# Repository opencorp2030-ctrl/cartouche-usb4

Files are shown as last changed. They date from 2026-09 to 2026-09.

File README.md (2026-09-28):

# CARTOUCHE Éclair V1 — a tiny USB4 NVMe drive for a local AI

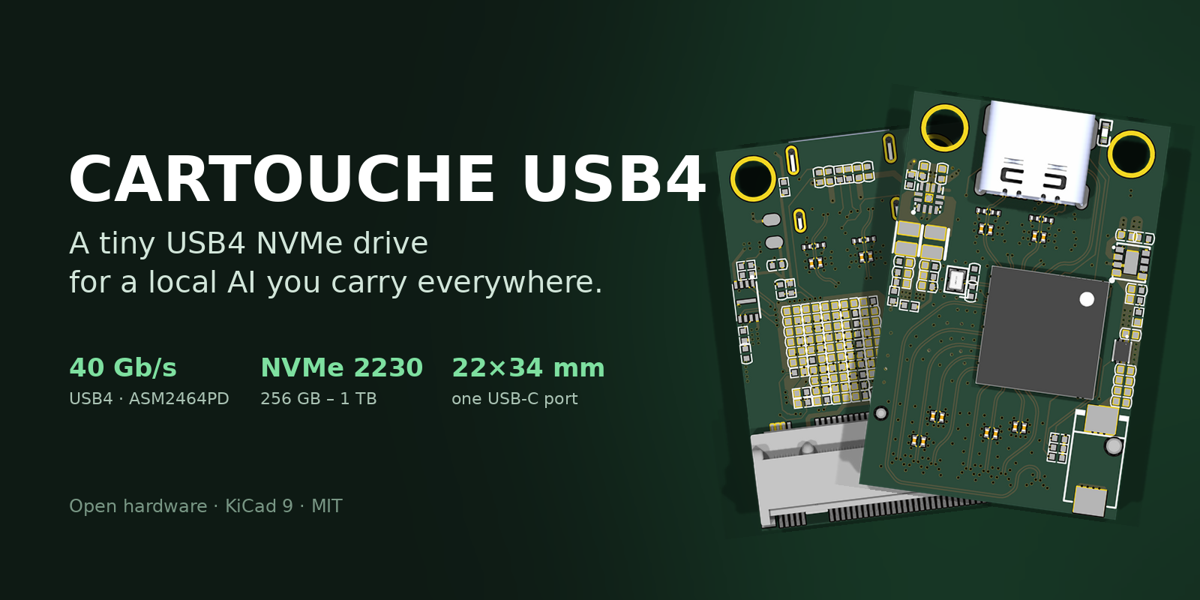
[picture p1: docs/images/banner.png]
CARTOUCHE Éclair V1


CARTOUCHE is a way to store heavy AI models and run them easily and fast, while
keeping your data from going to third-party servers.

Website: [cartouche.candygate.eu](https://cartouche.candygate.eu/eclair.html)

| | |
|---|---|
| Board | 22.0 × 33.7 mm, 4 layers, 1.6 mm |
| USB4 controller | ASMedia ASM2464PD, 40 Gb/s, PCIe 4.0 x4 |
| Storage | M.2 2230 NVMe SSD, 256 GB – 2 TB |
| Case | aluminium, 25 × 65.7 × 15.6 mm with the cooling fins, laser-engraved, 3 colours |
| Expected speed | ≈ 3.5 GB/s on USB4 / Thunderbolt, ≈ 1 GB/s on USB 3.2 (not measured yet) |
| In the box | USB-C 40 Gb/s cable + USB-A cable |

| Full model | Inside (case transparent) |
|---|---|
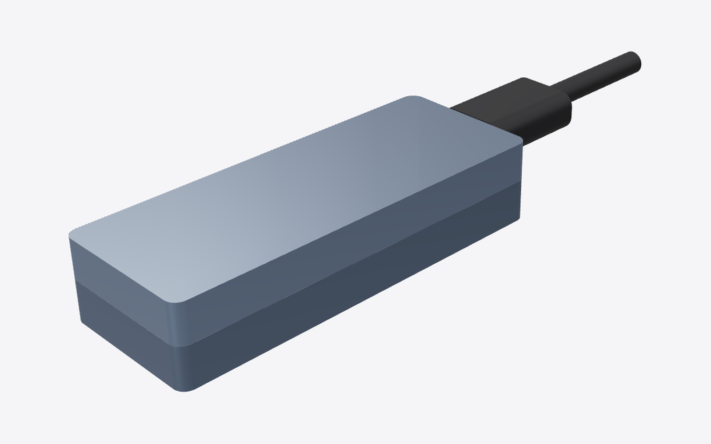
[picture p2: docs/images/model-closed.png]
full model
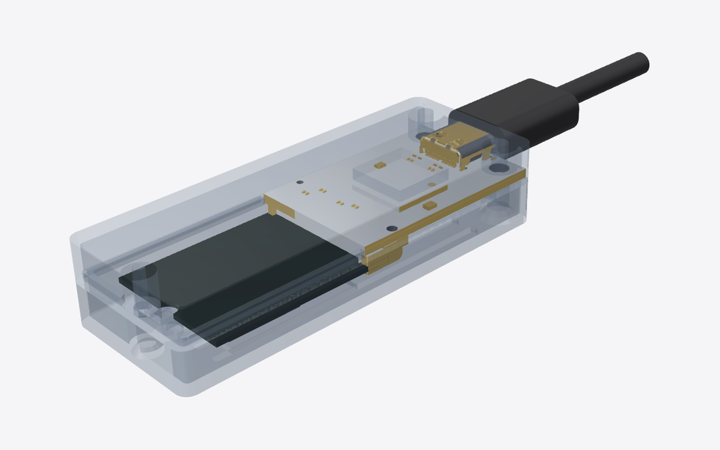
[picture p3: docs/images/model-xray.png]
inside
|  |  |
| **Exploded view** | **Board + SSD** |
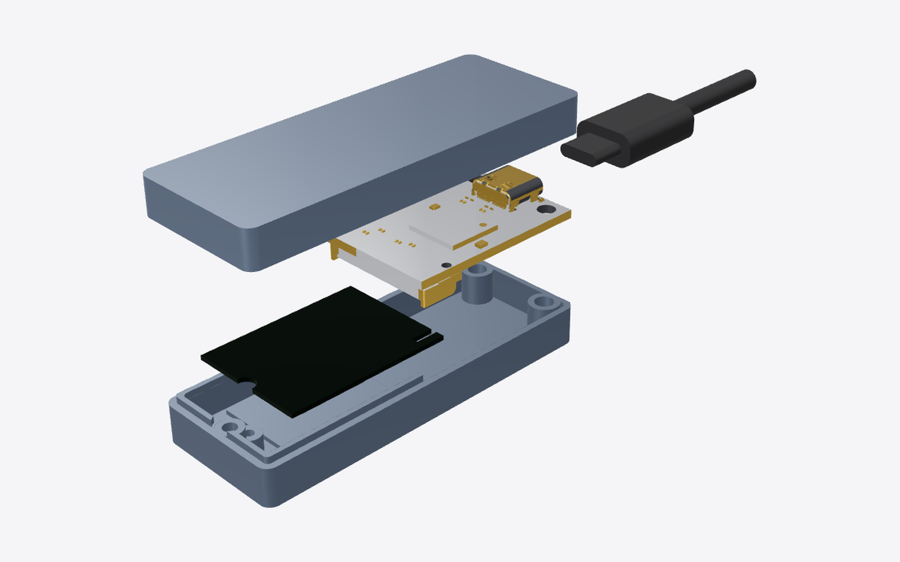
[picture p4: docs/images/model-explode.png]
exploded
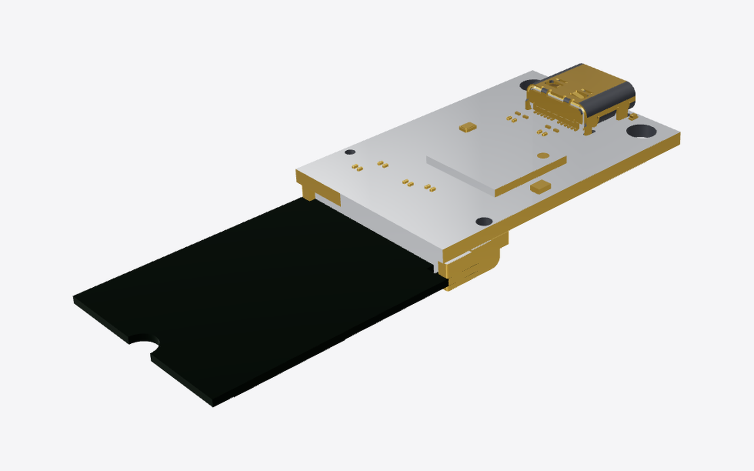
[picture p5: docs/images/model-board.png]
board and SSD
|  |  |
| **Cut through the middle** | **Underside, M3 screws** |
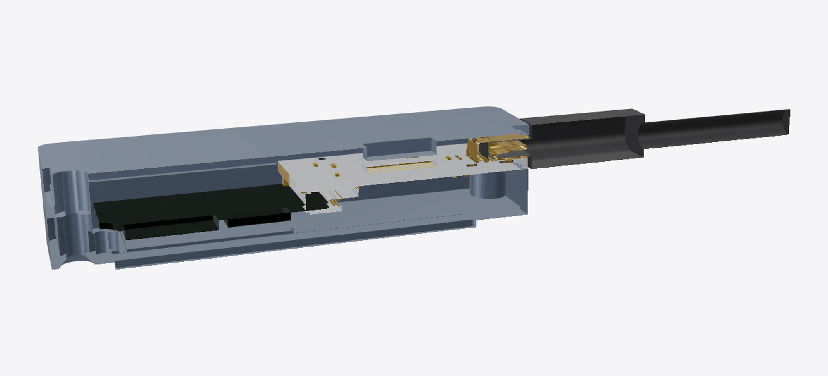
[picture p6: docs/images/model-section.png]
section
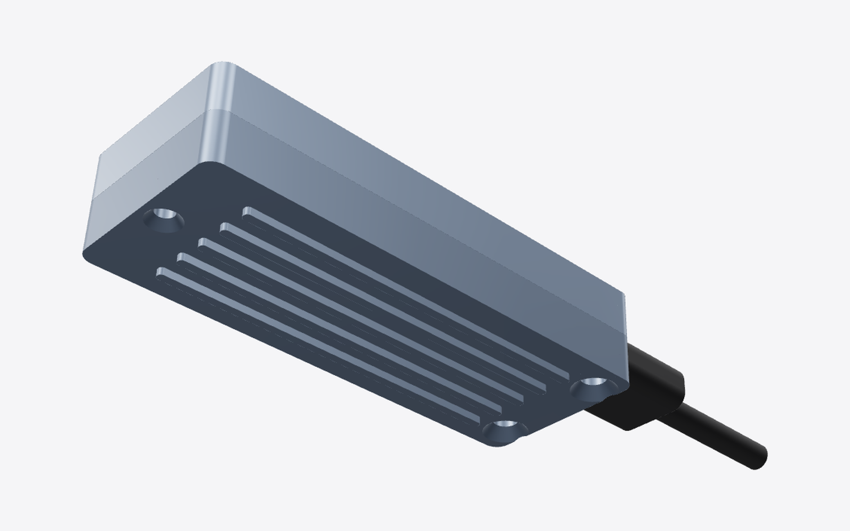
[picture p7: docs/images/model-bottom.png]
underside
|  |  |

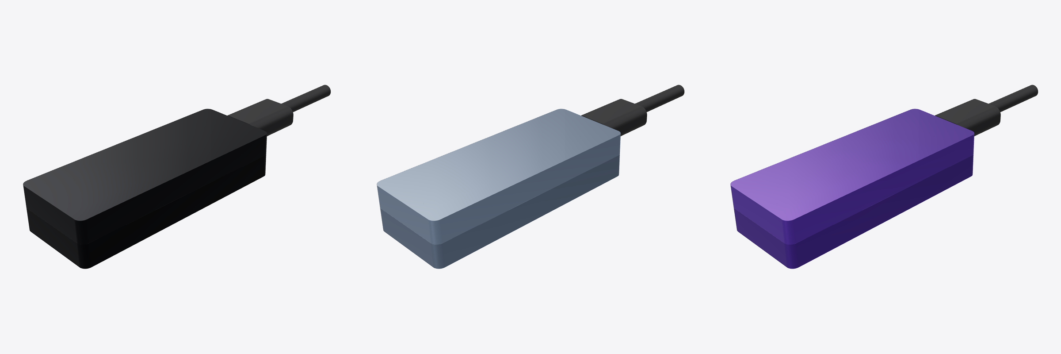
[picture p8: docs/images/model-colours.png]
three colours


| PCB, top | PCB, bottom |
|---|---|
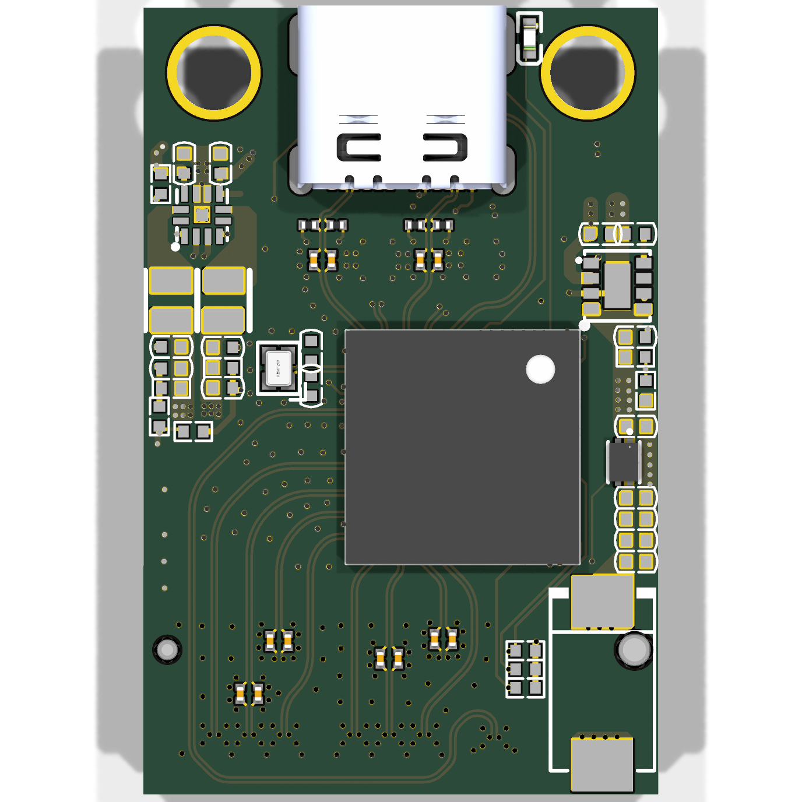
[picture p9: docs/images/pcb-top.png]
PCB top
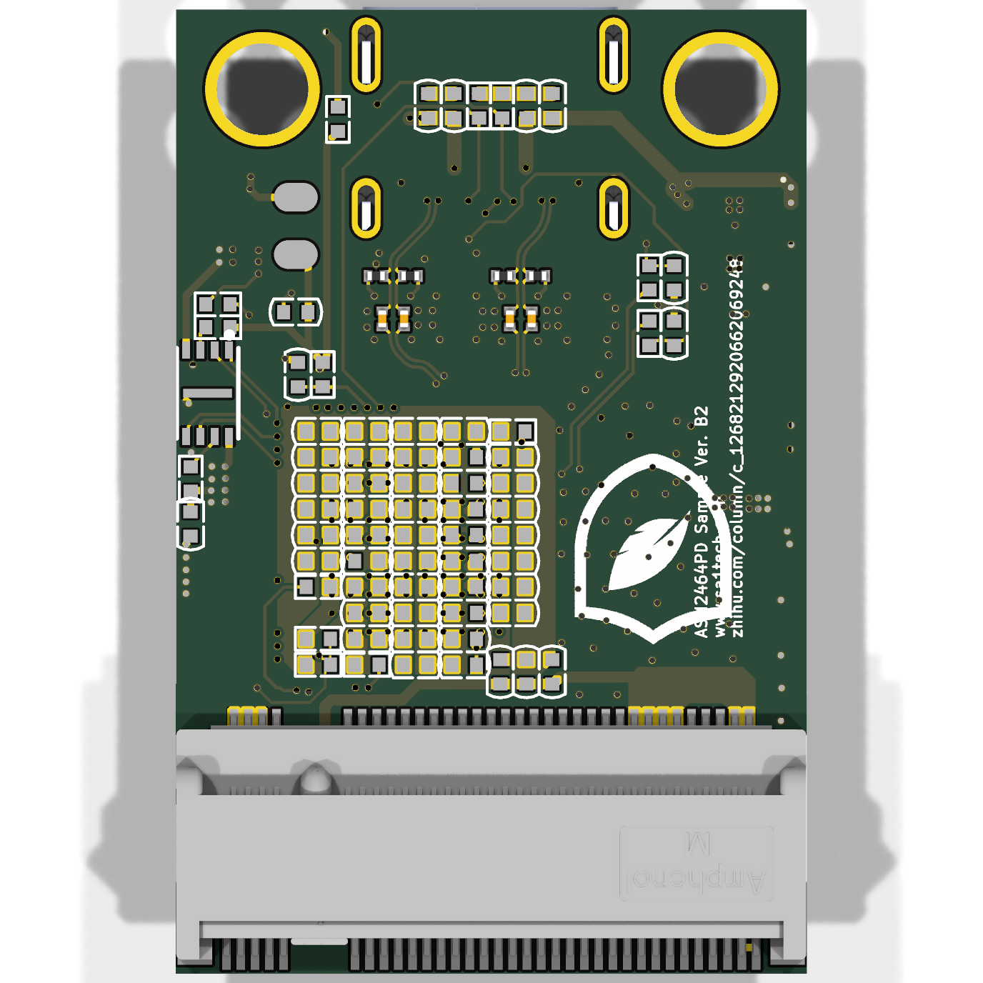
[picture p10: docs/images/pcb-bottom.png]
PCB bottom
|  |  |

## Why I made this

I got the idea because I have a lot of other projects with AI, and this was a real
problem. I like solving the problems I have.

Why my own drive (Éclair) and not just USB keys: because I want it to be useful
for devs and to be a good deal. That's actually why I set up the developer program.

## Wiring

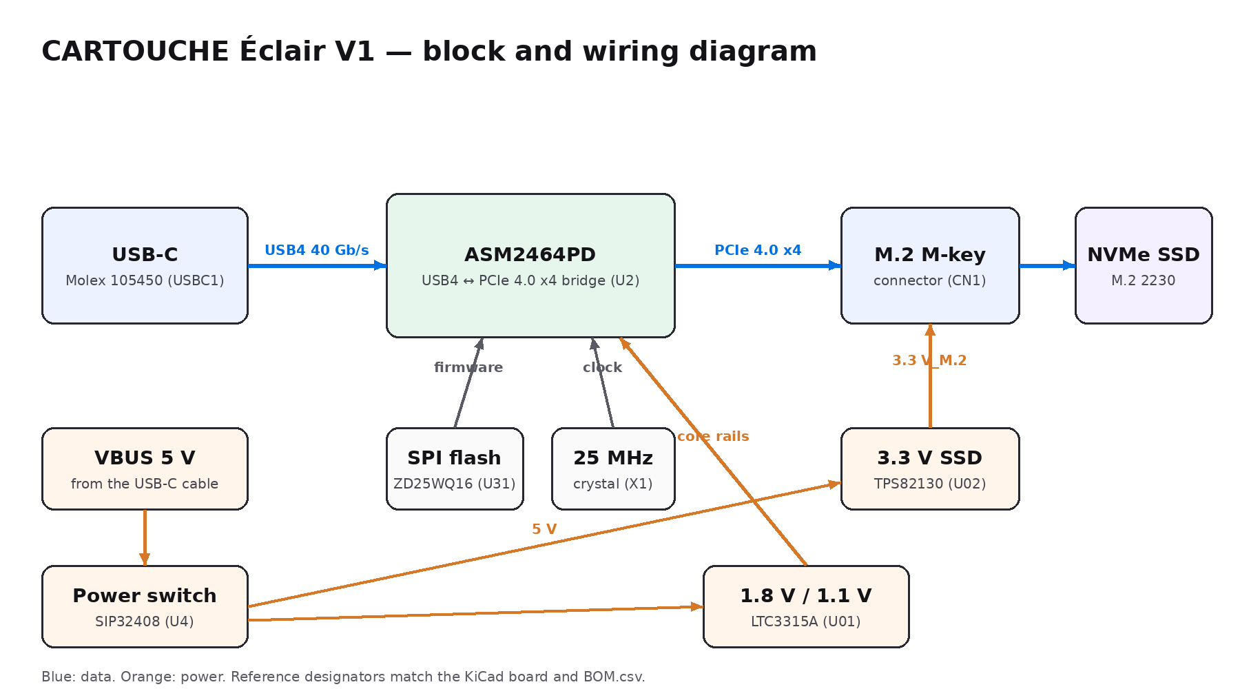
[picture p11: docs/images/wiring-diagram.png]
wiring diagram


Full schematic: [`pcb/cartouche-usb4.kicad_sch`](pcb/cartouche-usb4.kicad_sch) ·
[PDF](docs/schematic.pdf)

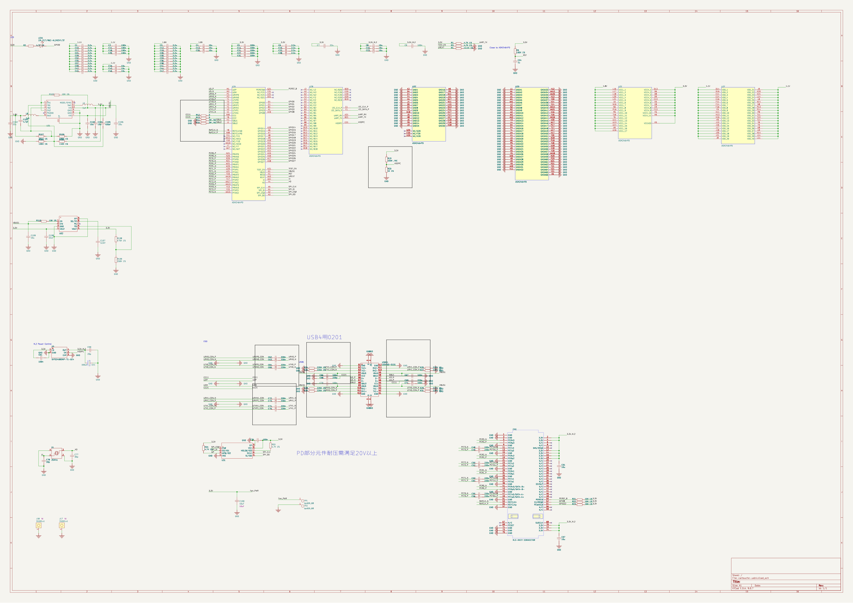
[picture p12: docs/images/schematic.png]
schematic


## What's in the repository

| Folder | Content |
|---|---|
| [`BOM.csv`](BOM.csv) | every part, with manufacturer part numbers and supplier links that work from France |
| [`pcb/`](pcb) | KiCad 9 project (`.kicad_pro`, `.kicad_sch`, `.kicad_pcb`, symbol library), Gerbers + drills (`fab/cartouche-usb4-gerbers.zip`), pick-and-place, board STEP, import scripts |
| [`cad/`](cad) | **case source** (`eclair_v1.py`, CadQuery), and in `cad/out/`: case base and lid, SSD 2230 and USB-C plug (STEP + STL), the board as a printable mock-up (STL), and **`eclair_v1_assembly.step`, the full assembly with the electronics** |
| [`firmware/`](firmware) | how the drive enumerates (NVMe over USB4, UAS over USB 3), flashing the ASMedia firmware, `eclair_check.py` (link and speed check) |
| [`docs/`](docs) | [costs per unit](docs/COSTS.md), images |

## The case

The case will be made of good-quality aluminium, both to protect against shocks and
to get rid of the heat. It will be engraved so the info doesn't wear off over time.
Arranging everything as well as possible is pretty complicated. I'm really happy
with it, especially the purple colour of the case, which you can pick as an option
on the website.

| Part | Detail |
|---|---|
| Halves | base + lid, split under the board |
| Board + closing | 2 × M3 × 12 countersunk screws, from below, through the board's Ø3.2 holes into the lid |
| SSD | in the M.2 connector (LOTES APCI0113-P001A, 4.75 mm, since v1.3: the ARGOSY NASM0-S6701-TPH4 is out of stock): card 3.15 mm under the board, edge seated 1.75 mm past the connector posts (LOTES drawing AP-APCI0113, to confirm on the real part); M2 screw on a standoff of the base |
| Assembly order | plug the SSD into the board outside the case, press it flat, lay board + SSD into the base, M2 screw, then the lid |
| Rear | 1 × M2 × 10 screw |
| USB-C | receptacle flush with the front; plug model included, mated and checked |
| Cooling (passive, no fan) | lid boss + 1 mm thermal pad on the ASM2464PD; base boss + 1 mm thermal pad (20 × 22 mm) under the SSD; 5 fins under the base (1 mm). Leaves232 warns the ASM2464PD overheats and disconnects without cooling (he used a laptop fan): to be checked with a 15 min transfer on the aluminium prototype |
| Interference check | no overlap between board, SSD, plug, base and lid |
| Fit test | print `case_base.stl`, `case_lid.stl`, `ssd_2230.stl`, `board_mockup.stl` (the mock-up has a 1.0 mm card slot cut in the connector); values to confirm are marked `CHECK` in `eclair_v1.py` |
| Fit check (CadQuery) | 0 mm³ overlap between SSD, board, case base, lid and USB-C plug |

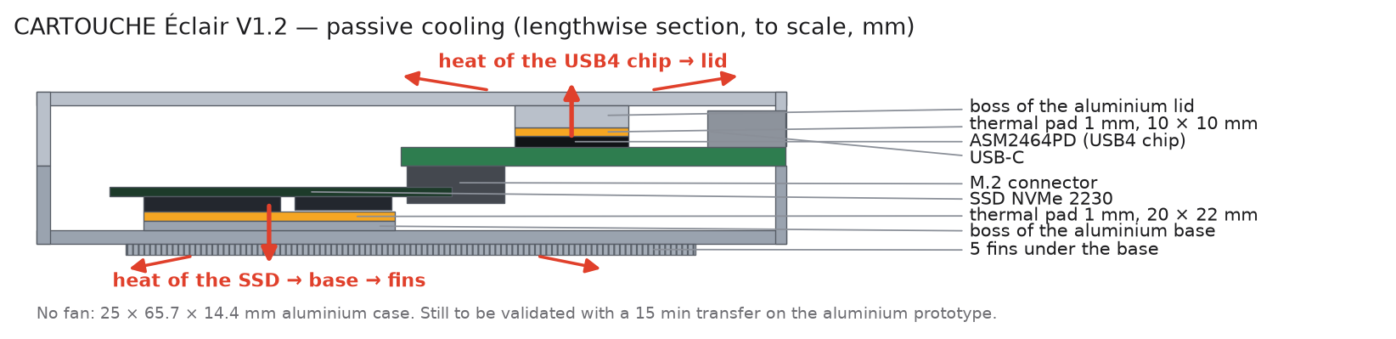
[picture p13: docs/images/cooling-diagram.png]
cooling diagram


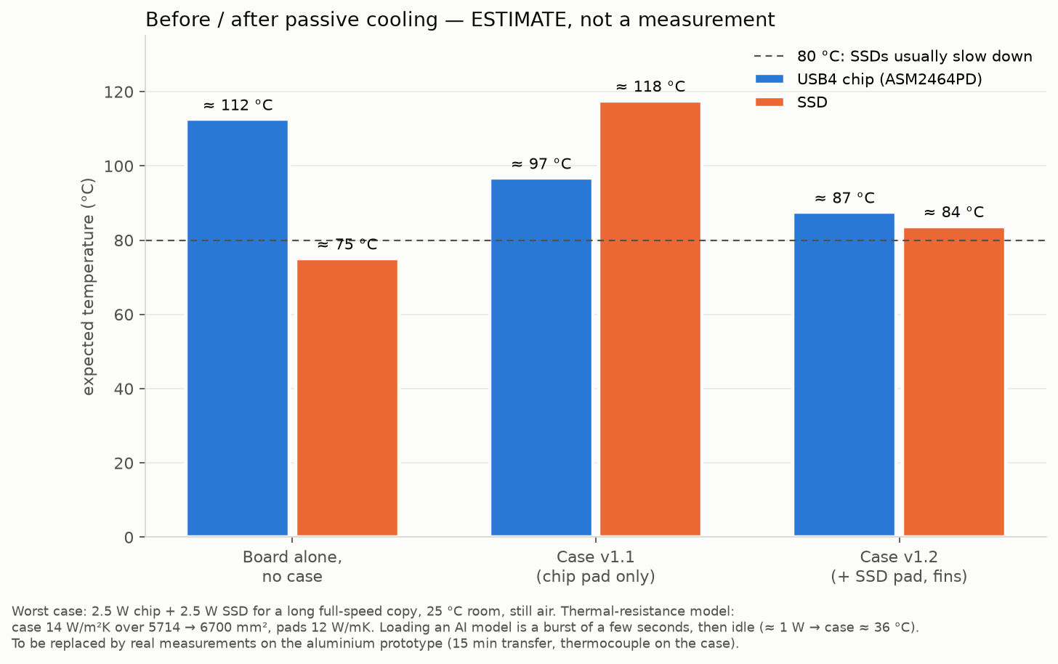
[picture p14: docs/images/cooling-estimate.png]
cooling estimate, before / after


The chart is an estimate from a simple thermal-resistance model (assumptions under the chart), not a measurement.

## Éclair Dock (optional): under the desk

| Top: Éclair slides in | Desk side: rails, screw bosses, air slots |
|---|---|
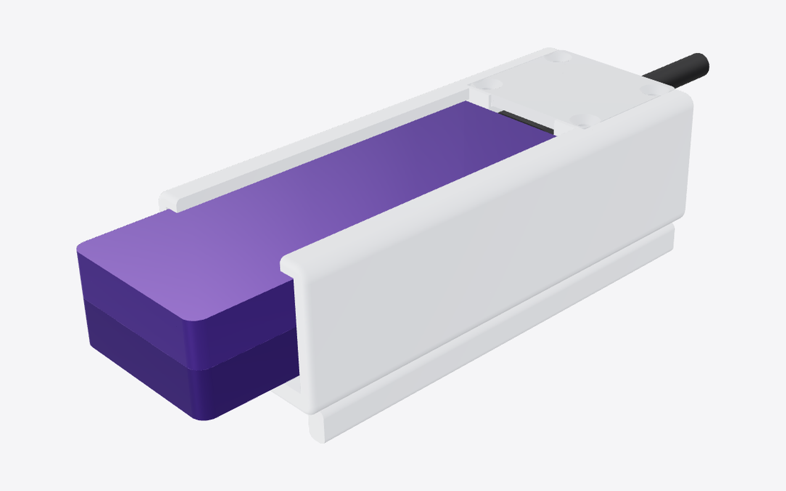
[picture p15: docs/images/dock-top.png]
dock top
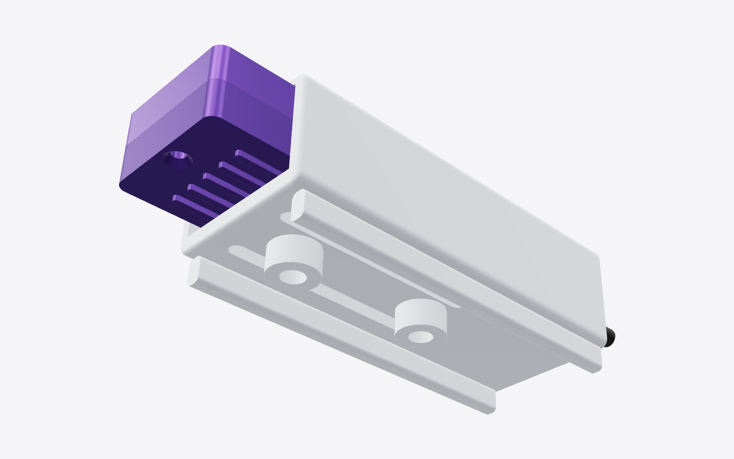
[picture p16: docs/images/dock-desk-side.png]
dock desk side
|  |  |

| Part | Detail |
|---|---|
| Size | 29.9 × 73.8 × 27.2 mm, CNC aluminium, polished |
| Mounting | 2 countersunk wood screws Ø4 under the desk (reachable with Éclair out) |
| Holding Éclair | Éclair hangs upside down on two lips (engraved lid facing the room), 0.25 mm clearance, 14 mm sticks out to grip it |
| Cable | USB4 40 Gb/s 0.8 m cable, its plug clamped in the rear block (plate + 4 × M2 countersunk): sliding Éclair in plugs it, pulling it out unplugs it |
| Airflow | 2 rails + 2 bosses keep the plate 5 mm off the desk; slots above the fins let warm air out along that gap (see diagram) |
| Fit check (CadQuery) | 0 mm³ overlap between dock, clamp, case and plug |
| Files | `cad/out/dock_body.step/.stl`, `dock_clamp.step/.stl`, `eclair_dock_assembly.step` (with the electronics) |

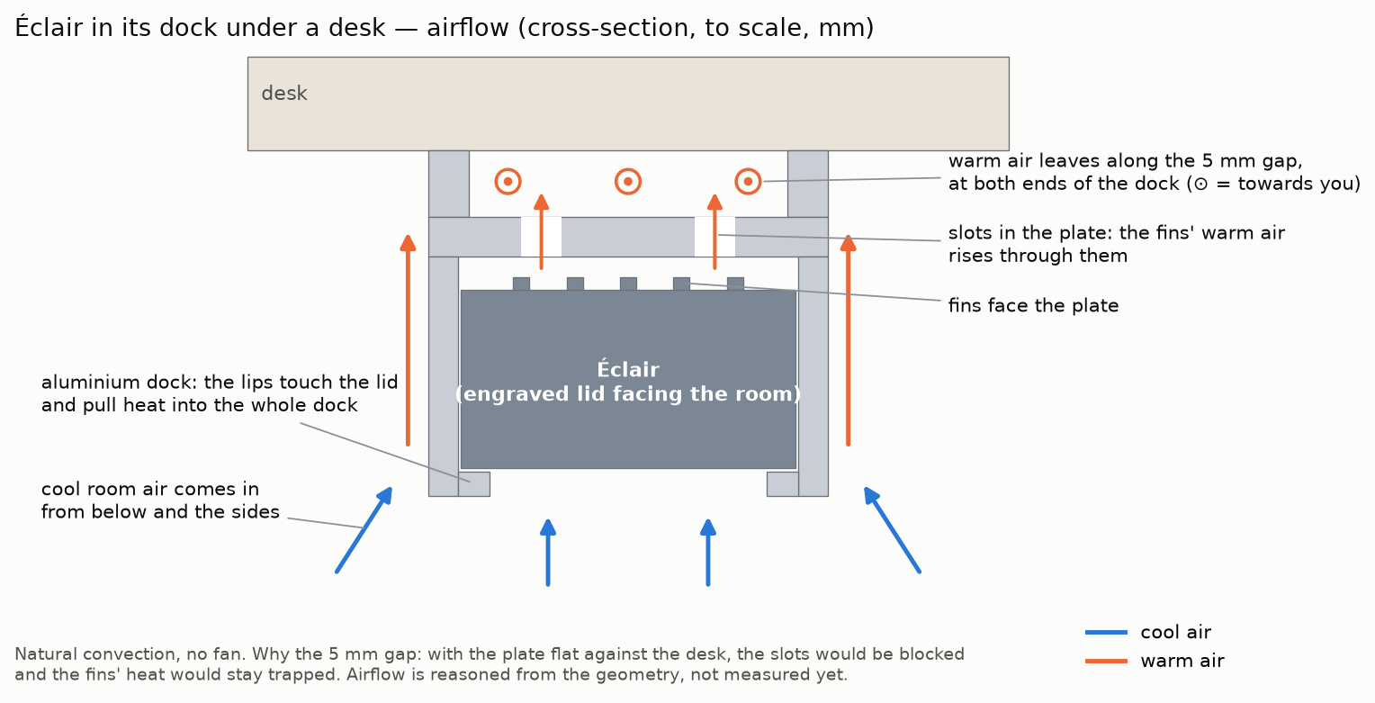
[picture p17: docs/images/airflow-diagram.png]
airflow under the desk


**Installing it**: a 1:1 drilling template is in [`docs/dock-drilling-template.pdf`](docs/dock-drilling-template.pdf) (print at 100 %, check the 50 mm bar; generated from the CAD numbers by `cad/make_dock_template.py`). Pilot holes Ø2.5 × 14 mm, desk top 18 mm thick minimum.

**Print test**: print `cad/out/dock_body.stl` (rails flat on the bed), `dock_clamp.stl`, `case_base.stl` and `case_lid.stl` in PLA/PETG, 0.2 mm layers. The 0.25 mm clearance is meant for machined aluminium; on an FDM print, sand the lips lightly if Éclair rubs.

3D films of the dock (object, installation, everyday use, cooling): https://cartouche.candygate.eu/support.html

## Credit: what is mine and what is not

For this prototype, I'd rather start from something that works, even if I have to
adjust it, than start again from zero (no need to reinvent the wheel). All the
ideas, the tests and the code are my work ;)

| From [Leaves232/2230-USB4-SSD-Enclosure-Design](https://github.com/Leaves232/2230-USB4-SSD-Enclosure-Design) (MIT, see [`LICENSE-upstream-MIT`](LICENSE-upstream-MIT)) | Mine |
|---|---|
| schematic, component placement, USB4/PCIe routing (not modified) | KiCad 9 conversion and fab package, smallest outline, case CAD, SSD and cable fit, BOM with suppliers and costs, flashing procedure and check tool, the CARTOUCHE software |

Schematic imported from the original Altium project into KiCad 9
(`pcb/cartouche-usb4.kicad_sch`, symbols in `pcb/ASM2464PD-altium-import.kicad_sym`).

## How to get it made

| Board parameter | Value |
|---|---|
| Layers / material | 4 layers, FR-4 TG150, 1.6 mm |
| Finish / copper | ENIG, 1 oz outer / 0.5 oz inner |
| Impedance | 85 Ω differential pairs on the outer layers |
| Track / space, vias | 3.5 / 3.5 mil, 0.2 mm tented vias |
| Assembly | by the fab (ASM2464PD = 0.46 mm pitch BGA) |
| Copper zones | do not refill in KiCad (from the tested original) |

1. Order the board assembled (PCBA).
2. Plug the SSD, place the thermal pad.
3. Screw the board and SSD into the base, close the lid.
4. Flash the firmware once ([`firmware/`](firmware)).

## Status

We're working on testing our own Éclair boards, and then, why not, making a sort of
mini computer you plug into your PC that runs the model on its own RAM and its own
storage.

## Licence

MIT, like the original design. See [`LICENSE`](LICENSE) and
[`LICENSE-upstream-MIT`](LICENSE-upstream-MIT).

## Bill of materials

Same content as [`BOM.csv`](BOM.csv).

| # | Qty | Value | Package | Manufacturer | Part number | Unit price | Link |
|---|---|---|---|---|---|---|---|
| 1 | 3 | 22uF | C0402 | Samsung | GRM155R60J226ME11D | CNY 0.22275 | [link](https://www.lcsc.com/search?q=GRM155R60J226ME11D) |
| 2 | 15 | 10uF | C0402 | Samsung | CL05A106MQ5NUNC | CNY 0.02281 | [link](https://www.lcsc.com/search?q=CL05A106MQ5NUNC) |
| 3 | 26 | 2.2uf | C0402 | Samsung | CL05A225KP5NSNC | CNY 0.01346 | [link](https://www.lcsc.com/search?q=CL05A225KP5NSNC) |
| 4 | 16 | 100nF | C0402 | FH | 0402F104M500NT | CNY 0.00481 | [link](https://www.lcsc.com/search?q=0402F104M500NT) |
| 5 | 1 | 1uF | C0402 | FH | 0402X105K6R3NT | CNY 0.00766 | [link](https://www.lcsc.com/search?q=0402X105K6R3NT) |
| 6 | 12 | 220nF | C0201 | Murata | GRM033R60J224ME15D | CNY 0.00917 | [link](https://www.lcsc.com/search?q=GRM033R60J224ME15D) |
| 7 | 1 | 20pF | C0402 | Yageo | CC0402JRNPO9BN200 | CNY 0.00456 | [link](https://www.lcsc.com/search?q=CC0402JRNPO9BN200) |
| 8 | 4 | 330nF | C0201 | Murata | GRM033R60J334ME90D | CNY 0.05114 | [link](https://www.lcsc.com/search?q=GRM033R60J334ME90D) |
| 9 | 2 | 220pF | C0402 | FH | 0402B221K500NT | CNY 0.00433 | [link](https://www.lcsc.com/search?q=0402B221K500NT) |
| 10 | 2 | 30pF | C0402 | FH | 0402CG300J500NT | CNY 0.00454 | [link](https://www.lcsc.com/search?q=0402CG300J500NT) |
| 11 | 1 | 4.7pf | C0402 | FH | 0402CG4R7B500NT | CNY 0.00744 | [link](https://www.lcsc.com/search?q=0402CG4R7B500NT) |
| 12 | 1 | 6.8pf | C0402 | FH | 0402CG6R8C500NT | CNY 0.00420 | [link](https://www.lcsc.com/search?q=0402CG6R8C500NT) |
| 13 | 1 | 33u | C0402 | Murata | GRM155R60J226ME11D | CNY 0.67700 | [link](https://www.lcsc.com/search?q=GRM155R60J226ME11D) |
| 14 | 1 | 3.3nf | C0402 | FH | 0402B332K500NT | CNY 0.00382 | [link](https://www.lcsc.com/search?q=0402B332K500NT) |
| 15 | 1 | 330uF | CAP-SMD_L7.3-W4.3-R-RD | Panasonic | 6TPE330MAP | CNY 2.37008 | [link](https://www.lcsc.com/search?q=6TPE330MAP) |
| 16 | 1 | M.2-MKEY CONNECTOR | CONN-SMD_APCI0113-P001A | LOTES | APCI0113-P001A (H4.8) | USD 0.74 | [link](https://www.lcsc.com/product-detail/C841669.html) |
| 17 | 2 | 1uh | IND-SMD_L2.0-W1.6-B | cjiang | FTC201610S1R0MBCA | CNY 0.19611 | [link](https://www.lcsc.com/search?q=FTC201610S1R0MBCA) |
| 18 | 1 | Red LED 0402 | LED0402-RD | Everlight | 16-213SDRC/S530-A3/TR8 | see link | [link](https://www.lcsc.com/product-detail/C71911.html) |
| 19 | 5 | 4.7K 1% | R0402 | Uniohm | 0402WGF4701TCE | CNY 0.00219 | [link](https://www.lcsc.com/search?q=0402WGF4701TCE) |
| 20 | 1 | 12.1K 1% | R0402 | Uniohm | 0402WGF1212TCE | CNY 0.00212 | [link](https://www.lcsc.com/search?q=0402WGF1212TCE) |
| 21 | 3 | 100K 1% | R0402 | Uniohm | 0402WGF1003TCE | CNY 0.00200 | [link](https://www.lcsc.com/search?q=0402WGF1003TCE) |
| 22 | 2 | 0 | R0402 | Uniohm | 0402WGF0000TCE | CNY 0.00198 | [link](https://www.lcsc.com/search?q=0402WGF0000TCE) |
| 23 | 1 | 1K 1% | R0402 | Uniohm | 0402WGF1001TCE | CNY 0.00222 | [link](https://www.lcsc.com/search?q=0402WGF1001TCE) |
| 24 | 5 | 10K 1% | R0402 | Uniohm | 0402WGF1002TCE | CNY 0.00216 | [link](https://www.lcsc.com/search?q=0402WGF1002TCE) |
| 25 | 8 | 220K 1% | R0201 | Uniohm | 0201WMF2203TEE | CNY 0.00446 | [link](https://www.lcsc.com/search?q=0201WMF2203TEE) |
| 26 | 1 | 140K 1% | R0402 | Yageo | RC0402FR-07140KL | CNY 0.00279 | [link](https://www.lcsc.com/search?q=RC0402FR-07140KL) |
| 27 | 1 | 261K 1% | R0402 | UniOhm | 0402WGF2613TCE | CNY 0.00216 | [link](https://www.lcsc.com/search?q=0402WGF2613TCE) |
| 28 | 1 | 475K 1% | R0402 | Yageo | RC0402FR-07475KL | CNY 0.00446 | [link](https://www.lcsc.com/search?q=RC0402FR-07475KL) |
| 29 | 1 | 150K 1% | R0402 | Uniohm | 0402WGF1503TCE | CNY 0.00213 | [link](https://www.lcsc.com/search?q=0402WGF1503TCE) |
| 30 | 1 | LTC3315AEV#TRPBF | LQFN-12_L2.0-W2.0-P0.50-TL-EP0.7 | ADI | LTC3315AEV#TRPBF | CNY 16.64280 | [link](https://www.lcsc.com/search?q=LTC3315AEV%23TRPBF) |
| 31 | 1 | ASM2464PD | BGA-273 0.46 mm | ASMedia | ASM2464PD | USD 26.60 (Alibaba, 1-99 pcs) | [link](https://jlcpcb.com/partdetail/Asmedia-ASM2464PD/C7509569) |
| 32 | 1 | TPS82130SILR | USIP-8_L3.0-W2.8-P0.65-TL-EP | TI | TPS82130SILR | CNY 22.94600 | [link](https://www.lcsc.com/search?q=TPS82130SILR) |
| 33 | 1 | SIP32408DNP-T1-GE4 | SIP32408DNP-T1-GE4 | Vishay | SIP32408DNP-T1-GE4 | CNY 4.50360 | [link](https://www.lcsc.com/search?q=SIP32408DNP-T1-GE4) |
| 34 | 1 | ZD25WQ16CEIGR | USON-8_L3.0-W2.0-P0.50-BL-EP | Zetta(澜智) | ZD25WQ16CEIGR | CNY 1.02600 | [link](https://www.lcsc.com/search?q=ZD25WQ16CEIGR) |
| 35 | 1 | 105450-0101 | USB-C-SMD_TYPE-C-USB-18 | Molex | 105450-0101 | CNY 6.32500 | [link](https://www.lcsc.com/search?q=105450-0101) |
| 36 | 1 | 25MHz | CRYSTAL-SMD_4P-L1.6-W1.2-BL | YXC | X322525MSB4SI | CNY 0.29520 | [link](https://www.lcsc.com/search?q=X322525MSB4SI) |
| 37 | 1 | M.2 2230 NVMe SSD, PCIe 4.0, 256 GB – 2 TB | M.2 2230 M-key | Western Digital / Kioxia / Corsair | SN740 / BG6 / MP600 Mini | EUR 30–130 | [link](https://www.amazon.fr/s?k=ssd+m.2+2230+nvme) |
| 38 | 2 | M3 x 12 countersunk (ISO 10642) |  |  |  | ≈ EUR 0.10 | [link](https://www.amazon.fr/s?k=vis+M3+12mm+tete+fraisee) |
| 39 | 1 | M2 x 10 countersunk |  |  |  | ≈ EUR 0.10 | [link](https://www.amazon.fr/s?k=vis+M2+10mm+tete+fraisee) |
| 40 | 1 | M2 x 3 (M.2 SSD screw) |  |  |  | ≈ EUR 0.10 | [link](https://www.amazon.fr/s?k=vis+m.2+ssd+kit) |
| 41 | 1 | 1 mm, ≥ 12 W/mK, cut 10 x 10 mm (chip) + 20 x 22 mm (SSD) |  |  |  | ≈ EUR 0.40 | [link](https://www.amazon.fr/s?k=pad+thermique+1mm+12w) |
| 42 | 1 | case_base + case_lid (cad/out) | aluminium CNC anodised, or 3D print for tests |  |  | ≈ EUR 15–35 | [link](https://jlccnc.com) |
| 43 | 1 | USB-C to USB-C, USB4 40 Gb/s, 0.5 m |  | UGREEN or equivalent |  | ≈ EUR 15 | [link](https://www.amazon.fr/s?k=cable+usb4+40gbps+0.5m) |
| 44 | 1 | USB-A to USB-C, 10 Gb/s, 0.5 m |  |  |  | ≈ EUR 10 | [link](https://www.amazon.fr/s?k=cable+usb+a+usb+c+10gbps+0.5m) |
| 45 | 1 | Éclair Dock, CNC aluminium, polished (cad/out/dock_body.step) |  |  |  | ≈ EUR 35 | [link](https://jlccnc.com) |
| 46 | 1 | cable clamp plate (cad/out/dock_clamp.step) |  |  |  | ≈ EUR 5 | [link](https://jlccnc.com) |
| 47 | 1 | USB-C to USB-C, USB4 40 Gb/s, 0.8 m |  |  |  | ≈ EUR 15 | [link](https://www.amazon.fr/s?k=cable+usb4+40gbps+0.8m) |
| 48 | 2 | countersunk Ø4 × 16 |  |  |  | ≈ EUR 0.20 | [link](https://www.amazon.fr/s?k=vis+bois+tete+fraisee+4x16) |
| 49 | 4 | M2 × 5 countersunk |  |  |  | ≈ EUR 0.20 | [link](https://www.amazon.fr/s?k=vis+m2+fraisee) |
| **TOTAL** |  | **One CARTOUCHE Éclair V1 256 GB, all parts + case + cables + box (batch of 10)** |  |  |  | **≈ EUR 149.00** | [docs/COSTS.md](docs/COSTS.md) |
| **TOTAL** |  | **Éclair V1 256 GB + Éclair Dock** |  |  |  | **≈ EUR 206.50** | [docs/COSTS.md](docs/COSTS.md) |

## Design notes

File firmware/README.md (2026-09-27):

# Firmware and software

## How Éclair shows up

| Port | Seen by the computer as | Expected speed |
|---|---|---|
| USB4 / Thunderbolt 3–4 | native NVMe drive (PCIe tunnelled by the ASM2464PD) | ≈ 3.5 GB/s |
| USB 3.x, or with the USB-A cable | USB mass storage (UAS) | ≈ 1 GB/s |

- Driver: none needed (Windows, macOS, Linux).
- Firmware: ASMedia, closed source, in the SPI flash on the board (U31, ZD25WQ16). It can only be flashed and configured.

## Flashing a new board (once per board)

1. Get the firmware package and ASMedia's tool from
   [Leaves232/2230-USB4-SSD-Enclosure-Design](https://github.com/Leaves232/2230-USB4-SSD-Enclosure-Design)
   (`ASM2464PD_FW_250123_85_00_00.zip`). Not redistributed here (ASMedia's licence).
2. Plug the new board (with its SSD) into a Windows PC on a USB 3 port.
3. Run the ASMedia MP tool, load the firmware `.bin`, flash, unplug.
4. Plug it again: a new disk appears. Check it with `eclair_check.py`.

## eclair_check.py

Python 3, no dependency. Shows how the drive is connected (NVMe over USB4, or USB)
and measures sequential write and read speed with a test file.
Status: works on any drive; not run on real Éclair hardware yet (boards not built).

```
python eclair_check.py E:\                      # Windows
python3 eclair_check.py /media/you/CARTOUCHE    # Linux / macOS
```

## CARTOUCHE software

| Step | On Éclair |
|---|---|
| Runtime | same CARTOUCHE software as the USB keys (local AI runtime, chat interface, models) |
| Preparing the drive (CARTOUCHE Creator) | on a USB 3 port, where Éclair is a USB disk |
| Authenticity check | licence bound to the NVMe SSD's identity on USB4, or to the USB bridge on USB 3 (CARTOUCHE 1.0.9) |

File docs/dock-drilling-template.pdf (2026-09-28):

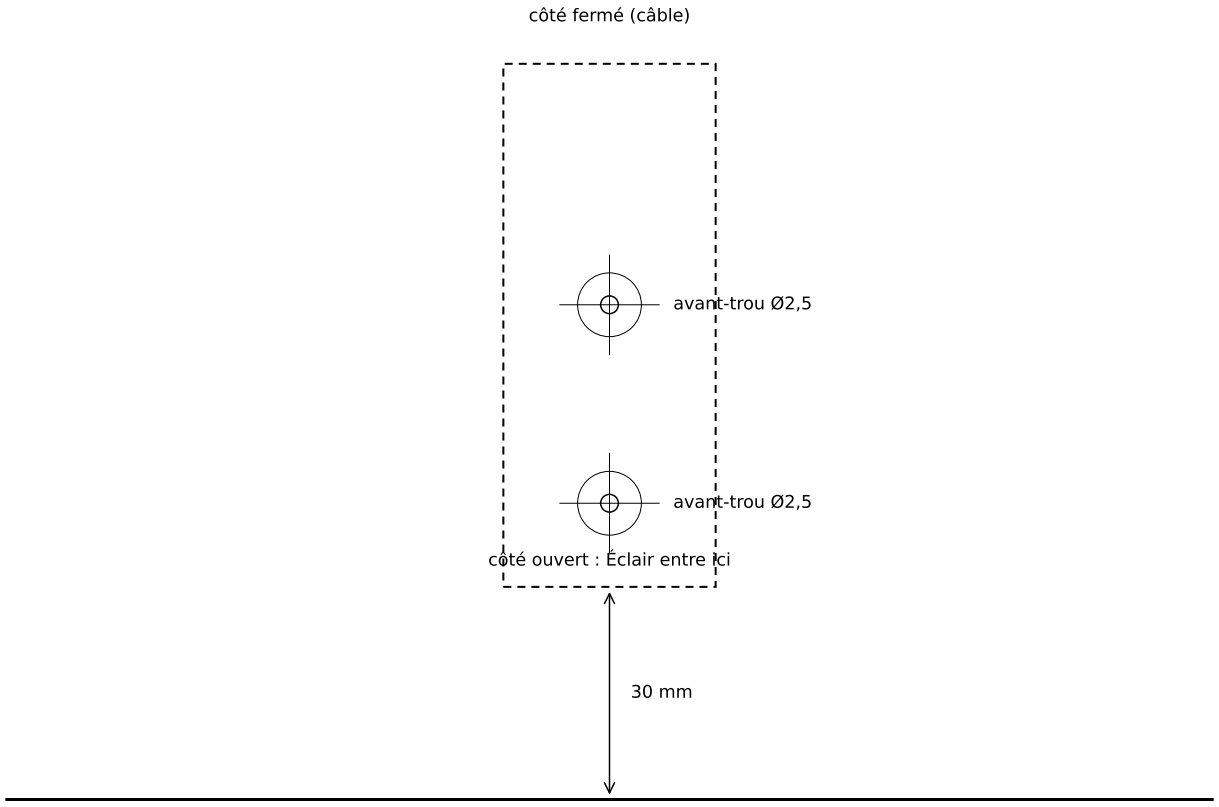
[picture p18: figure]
avant-trou Ø2,5; côté fermé (câble); côté ouvert : Éclair entre ici

### BORD DU BUREAU (côté où vous êtes assis)

# SUPPORT ÉCLAIR · GABARIT DE PERÇAGE 1:1

Imprimer à 100 % (taille réelle, sans « ajuster à la page »). Vérifier la barre de 50 mm.

50 mm

1. Scotcher le gabarit sous le bureau, la ligne du bas sur le bord.
2. Marquer les deux croix au crayon (ou pointer à travers).
3. Retirer le gabarit, percer Ø2,5 mm sur 14 mm (plateau de 18 mm d’épaisseur minimum).
4. Visser le support : 2 vis à bois Ø4 × 16 tête fraisée, sans forcer.

cartouche.candygate.eu/support-pose.html · d'après le modèle CAD (eclair_v1.py)

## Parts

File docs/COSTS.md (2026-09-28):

# Cost of one CARTOUCHE Éclair (USB4 drive), per capacity

**Real** = a quote or a public price · **estimate** = not quoted by a supplier yet.

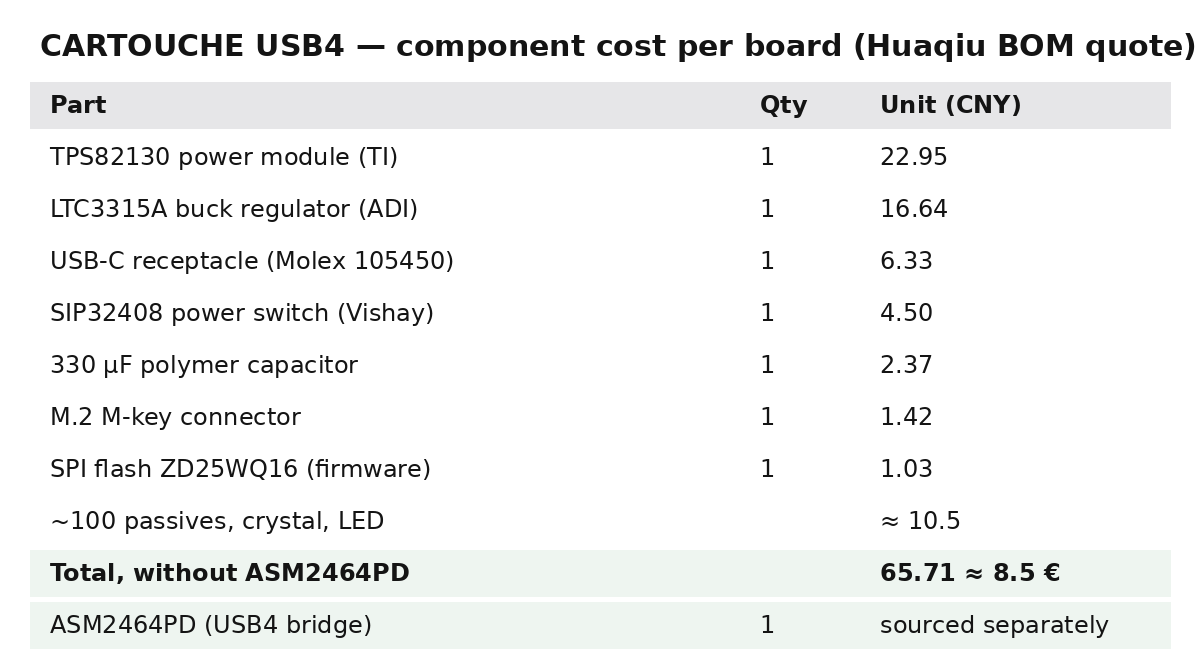
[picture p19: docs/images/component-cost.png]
component cost


## Complete board (PCB + parts + assembly)

| Item | First batch of 10 | Batch of 100 | Source |
|---|---|---|---|
| Parts except the USB4 chip | 8.50 € | 8.50 € | **real**: Huaqiu BOM quote, 65.71 CNY |
| ASM2464PD (USB4 chip) | 24.50 € ($26.60) | 23.60 € ($25.60) | **real**: Alibaba price for 1–99 / 100–499 pcs |
| Bare 4-layer PCB, 22 × 34 mm, controlled impedance | ≈ 12 € | ≈ 2.50 € | estimate (to re-quote with the new Gerbers) |
| Assembly (PCBA, BGA) | ≈ 10 € | ≈ 3 € | estimate (NextPCB advertises a free first assembly) |
| **Complete board** | **≈ 55 €** | **≈ 38 €** | |

## Everything around it

| Item | Batch of 10 | Batch of 100 | Source |
|---|---|---|---|
| Aluminium case, CNC, anodised, laser-engraved | ≈ 35 € | ≈ 15 € | estimate (to quote once the case is drawn) |
| Thermal pad + screws | 1 € | 1 € | estimate |
| USB-A → USB-C cable, 10 Gb/s, 0.5 m (any computer) | 10 € | 10 € | **real**: found by the maker |
| USB-C ↔ USB-C cable, USB4 40 Gb/s, 0.5 m (full speed) | ≈ 15 € | ≈ 15 € | **real** prices seen: 14.90 € (0.5 m), $13.99 (UGREEN 1 m, sale) |
| Box, foam, printed notice | ≈ 3 € | ≈ 3 € | estimate |
| Shipping, Colissimo home delivery, 250 g | 5.49 € | 5.49 € | **real**: La Poste 2026 rate (free for the customer above 59 €) |

## Per capacity: sold at cost

I think it's important to support the developers and teenagers who will be
interested, and I'm not especially trying to make a profit on this project.

- Price = unit cost + card fees (1.5 % + 0.25 €) + seller's social contributions (12.3 %) + 5 % reserve (faulty units, returns).
- Shipping: charged separately, at cost.
- Public breakdown: [cartouche.candygate.eu/nos-prix.html](https://cartouche.candygate.eu/nos-prix.html) (computed by `tools/prix_coutant.py`).
- SSD prices: retail estimates for an M.2 2230 NVMe (2 TB: $120–140 seen). Costs for the first batch of 10.

| Capacity | SSD | Unit cost (incl. box) | Price | Of which reserve |
|---|---|---|---|---|
| 256 GB | ≈ 30 € | 149 € | 184 € | 9.36 € |
| 512 GB | ≈ 45 € | 164 € | 203 € | 10.73 € |
| 1 TB | ≈ 80 € | 199 € | 246 € | 12.80 € |
| 2 TB | ≈ 130 € | 249 € | 307 € | 15.38 € |

- Batches of 100: board ≈ 38 €, case ≈ 15 € → prices about 45 € lower per unit.
- Not included: one-off costs of the first run (stencil, CNC programming) and prototype revisions; not paid by buyers.
- In the box: USB-A cable (any computer, ≈ 1 GB/s) + USB-C 40 Gb/s cable (full USB4 speed, ≈ 3.5 GB/s).

## What to buy besides the assembled board

- Assembler (NextPCB, turnkey PCBA): buys and solders every BOM part (regulators, USB-C and M.2 connectors, crystal, flash, passives).
- ASM2464PD: ask the assembler to source it (missing from the original BOM match); otherwise JLCPCB C7509569, or Alibaba ($26.60) sent as a consigned part.

Per drive, bought separately:

| Part | Where | Per drive |
|---|---|---|
| M.2 2230 NVMe SSD (256 GB – 2 TB), e.g. WD SN740, Kioxia BG6, Corsair MP600 Mini | retail | 30–130 € |
| Aluminium case, 2 halves, CNC + anodised + laser-engraved | CNC supplier (from the STEP model) | ≈ 15–35 € |
| Thermal pad 1 mm, ≥ 12 W/mK: cut 10 × 10 mm for the ASM2464PD, 22 × 20 mm for the SSD | one 100 × 100 mm sheet (≈ 10 €) does about 25 drives | ≈ 0.40 € |
| 2 × M3 × 12 countersunk (board + case), 1 × M2 × 10 (rear), 1 × M2 × 3 (SSD) | screw kits (≈ 1–10 €) | ≈ 0.30 € |
| USB-C 40 Gb/s cable + USB-A 10 Gb/s cable | retail | ≈ 25 € |
| Box, foam insert, printed notice | packaging supplier / print shop | ≈ 3 € |

One-off tools: a Windows PC to flash the ASMedia firmware (free tool from the original project), a USB4 or Thunderbolt computer to measure the real speed.

## Éclair Dock (optional, sold at cost)

| Item | Batch of 10 | Source |
|---|---|---|
| Dock body + clamp, CNC aluminium, polished | ≈ 40 € | estimate (to quote from the STEP files) |
| USB4 40 Gb/s cable, 0.8 m | ≈ 15 € | retail price |
| Screws (2 wood, 4 × M2) | ≈ 0.50 € | estimate |
| Box and fitting notice | ≈ 2 € | estimate |
| **Unit cost / price at cost** | **≈ 57.50 € / 72 €** | computed by `tools/prix_coutant.py` |

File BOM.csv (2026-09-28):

Item | Qty per unit | Reference | Value | Package | Manufacturer | Manufacturer part number | Supplier link (ships to France) | Unit price | Bought by | Note
1 | 3 | C7, C102,C108 | 22uF | C0402 | Samsung | GRM155R60J226ME11D | https://www.lcsc.com/search?q=GRM155R60J226ME11D | CNY 0.22275 | assembler (turnkey PCBA)
2 | 15 | C4, C8, C13, C16, C20, C23, C40, C43, C46, C51, C57, C103, C104, C109,C100 | 10uF | C0402 | Samsung | CL05A106MQ5NUNC | https://www.lcsc.com/search?q=CL05A106MQ5NUNC | CNY 0.02281 | assembler (turnkey PCBA)
3 | 26 | C1, C3, C6, C10, C12, C15, C17, C19, C22, C24, C26, C28, C29, C30, C32, C33, C35, C36, C37, C38, C39, C41, C42, C44, C45, C47 | 2.2uf | C0402 | Samsung | CL05A225KP5NSNC | https://www.lcsc.com/search?q=CL05A225KP5NSNC | CNY 0.01346 | assembler (turnkey PCBA)
4 | 16 | C2, C5, C9, C11, C14, C18, C21, C25, C27, C31, C61, C66, C67, C70, C71, C76 | 100nF | C0402 | FH | 0402F104M500NT | https://www.lcsc.com/search?q=0402F104M500NT | CNY 0.00481 | assembler (turnkey PCBA)
5 | 1 | C34 | 1uF | C0402 | FH | 0402X105K6R3NT | https://www.lcsc.com/search?q=0402X105K6R3NT | CNY 0.00766 | assembler (turnkey PCBA)
6 | 12 | C48, C49, C50, C52, C53, C54, C55, C56, C64, C65, C74, C75 | 220nF | C0201 | Murata | GRM033R60J224ME15D | https://www.lcsc.com/search?q=GRM033R60J224ME15D | CNY 0.00917 | assembler (turnkey PCBA)
7 | 1 | C59 | 20pF | C0402 | Yageo | CC0402JRNPO9BN200 | https://www.lcsc.com/search?q=CC0402JRNPO9BN200 | CNY 0.00456 | assembler (turnkey PCBA)
8 | 4 | C62, C63, C72, C73 | 330nF | C0201 | Murata | GRM033R60J334ME90D | https://www.lcsc.com/search?q=GRM033R60J334ME90D | CNY 0.05114 | assembler (turnkey PCBA)
9 | 2 | C68, C69 | 220pF | C0402 | FH | 0402B221K500NT | https://www.lcsc.com/search?q=0402B221K500NT | CNY 0.00433 | assembler (turnkey PCBA)
10 | 2 | C77, C78 | 30pF | C0402 | FH | 0402CG300J500NT | https://www.lcsc.com/search?q=0402CG300J500NT | CNY 0.00454 | assembler (turnkey PCBA)
11 | 1 | C101 | 4.7pf | C0402 | FH | 0402CG4R7B500NT | https://www.lcsc.com/search?q=0402CG4R7B500NT | CNY 0.00744 | assembler (turnkey PCBA)
12 | 1 | C105 | 6.8pf | C0402 | FH | 0402CG6R8C500NT | https://www.lcsc.com/search?q=0402CG6R8C500NT | CNY 0.00420 | assembler (turnkey PCBA)
13 | 1 | C106 | 33u | C0402 | Murata | GRM155R60J226ME11D | https://www.lcsc.com/search?q=GRM155R60J226ME11D | CNY 0.67700 | assembler (turnkey PCBA)
14 | 1 | C107 | 3.3nf | C0402 | FH | 0402B332K500NT | https://www.lcsc.com/search?q=0402B332K500NT | CNY 0.00382 | assembler (turnkey PCBA)
15 | 1 | CE1 | 330uF | CAP-SMD_L7.3-W4.3-R-RD | Panasonic | 6TPE330MAP | https://www.lcsc.com/search?q=6TPE330MAP | CNY 2.37008 | assembler (turnkey PCBA)
16 | 1 | CN1 | M.2-MKEY CONNECTOR | CONN-SMD_APCI0113-P001A | LOTES | APCI0113-P001A (H4.8) | https://www.lcsc.com/product-detail/C841669.html | USD 0.74 | assembler (turnkey PCBA)
17 | 2 | L5, L6 | 1uh | IND-SMD_L2.0-W1.6-B | cjiang | FTC201610S1R0MBCA | https://www.lcsc.com/search?q=FTC201610S1R0MBCA | CNY 0.19611 | assembler (turnkey PCBA)
18 | 1 | LED1 | Red LED 0402 | LED0402-RD | Everlight | 16-213SDRC/S530-A3/TR8 | https://www.lcsc.com/product-detail/C71911.html |  | assembler (turnkey PCBA)
19 | 5 | R1, R2, R3, R33, R34 | 4.7K 1% | R0402 | Uniohm | 0402WGF4701TCE | https://www.lcsc.com/search?q=0402WGF4701TCE | CNY 0.00219 | assembler (turnkey PCBA)
20 | 1 | R4 | 12.1K 1% | R0402 | Uniohm | 0402WGF1212TCE | https://www.lcsc.com/search?q=0402WGF1212TCE | CNY 0.00212 | assembler (turnkey PCBA)
21 | 3 | R6, R104, R106 | 100K 1% | R0402 | Uniohm | 0402WGF1003TCE | https://www.lcsc.com/search?q=0402WGF1003TCE | CNY 0.00200 | assembler (turnkey PCBA)
22 | 2 | R12, R13 | 0 | R0402 | Uniohm | 0402WGF0000TCE | https://www.lcsc.com/search?q=0402WGF0000TCE | CNY 0.00198 | assembler (turnkey PCBA)
23 | 1 | R20 | 1K 1% | R0402 | Uniohm | 0402WGF1001TCE | https://www.lcsc.com/search?q=0402WGF1001TCE | CNY 0.00222 | assembler (turnkey PCBA)
24 | 5 | R21, R22, R23, R103, R110 | 10K 1% | R0402 | Uniohm | 0402WGF1002TCE | https://www.lcsc.com/search?q=0402WGF1002TCE | CNY 0.00216 | assembler (turnkey PCBA)
25 | 8 | R24, R25, R26, R27, R28, R29, R30, R31 | 220K 1% | R0201 | Uniohm | 0201WMF2203TEE | https://www.lcsc.com/search?q=0201WMF2203TEE | CNY 0.00446 | assembler (turnkey PCBA)
26 | 1 | R105 | 140K 1% | R0402 | Yageo | RC0402FR-07140KL | https://www.lcsc.com/search?q=RC0402FR-07140KL | CNY 0.00279 | assembler (turnkey PCBA)
27 | 1 | R107 | 261K 1% | R0402 | UniOhm | 0402WGF2613TCE | https://www.lcsc.com/search?q=0402WGF2613TCE | CNY 0.00216 | assembler (turnkey PCBA)
28 | 1 | R108 | 475K 1% | R0402 | Yageo | RC0402FR-07475KL | https://www.lcsc.com/search?q=RC0402FR-07475KL | CNY 0.00446 | assembler (turnkey PCBA)
29 | 1 | R109 | 150K 1% | R0402 | Uniohm | 0402WGF1503TCE | https://www.lcsc.com/search?q=0402WGF1503TCE | CNY 0.00213 | assembler (turnkey PCBA)
30 | 1 | U01 | LTC3315AEV#TRPBF | LQFN-12_L2.0-W2.0-P0.50-TL-EP0.7 | ADI | LTC3315AEV#TRPBF | https://www.lcsc.com/search?q=LTC3315AEV%23TRPBF | CNY 16.64280 | assembler (turnkey PCBA)
31 | 1 | U2 | ASM2464PD | BGA-273 0.46 mm | ASMedia | ASM2464PD | https://jlcpcb.com/partdetail/Asmedia-ASM2464PD/C7509569 | USD 26.60 (Alibaba, 1-99 pcs) | assembler (or consigned) | USB4 to PCIe 4.0 x4 bridge
32 | 1 | U02 | TPS82130SILR | USIP-8_L3.0-W2.8-P0.65-TL-EP | TI | TPS82130SILR | https://www.lcsc.com/search?q=TPS82130SILR | CNY 22.94600 | assembler (turnkey PCBA)
33 | 1 | U4 | SIP32408DNP-T1-GE4 | SIP32408DNP-T1-GE4 | Vishay | SIP32408DNP-T1-GE4 | https://www.lcsc.com/search?q=SIP32408DNP-T1-GE4 | CNY 4.50360 | assembler (turnkey PCBA)
34 | 1 | U31 | ZD25WQ16CEIGR | USON-8_L3.0-W2.0-P0.50-BL-EP | Zetta(澜智) | ZD25WQ16CEIGR | https://www.lcsc.com/search?q=ZD25WQ16CEIGR | CNY 1.02600 | assembler (turnkey PCBA)
35 | 1 | USBC1 | 105450-0101 | USB-C-SMD_TYPE-C-USB-18 | Molex | 105450-0101 | https://www.lcsc.com/search?q=105450-0101 | CNY 6.32500 | assembler (turnkey PCBA)
36 | 1 | X1 | 25MHz | CRYSTAL-SMD_4P-L1.6-W1.2-BL | YXC | X322525MSB4SI | https://www.lcsc.com/search?q=X322525MSB4SI | CNY 0.29520 | assembler (turnkey PCBA)
37 | 1 | SSD | M.2 2230 NVMe SSD, PCIe 4.0, 256 GB – 2 TB | M.2 2230 M-key | Western Digital / Kioxia / Corsair | SN740 / BG6 / MP600 Mini | https://www.amazon.fr/s?k=ssd+m.2+2230+nvme | EUR 30–130 | maker | plugs in by hand
38 | 2 | Screws | M3 x 12 countersunk (ISO 10642) |  |  |  | https://www.amazon.fr/s?k=vis+M3+12mm+tete+fraisee | ≈ EUR 0.10 | maker | base + board + lid (board holes Ø3.2)
39 | 1 | Screw | M2 x 10 countersunk |  |  |  | https://www.amazon.fr/s?k=vis+M2+10mm+tete+fraisee | ≈ EUR 0.10 | maker | rear closing screw
40 | 1 | Screw | M2 x 3 (M.2 SSD screw) |  |  |  | https://www.amazon.fr/s?k=vis+m.2+ssd+kit | ≈ EUR 0.10 | maker | holds the SSD on the standoff
41 | 1 | Thermal pad | 1 mm, ≥ 12 W/mK, cut 10 x 10 mm (chip) + 20 x 22 mm (SSD) |  |  |  | https://www.amazon.fr/s?k=pad+thermique+1mm+12w | ≈ EUR 0.40 | maker | between the ASM2464PD and the lid boss, and between the SSD and the base boss
42 | 1 | Case | case_base + case_lid (cad/out) | aluminium CNC anodised, or 3D print for tests |  |  | https://jlccnc.com | ≈ EUR 15–35 | maker | laser-engraved lid
43 | 1 | Cable | USB-C to USB-C, USB4 40 Gb/s, 0.5 m |  | UGREEN or equivalent |  | https://www.amazon.fr/s?k=cable+usb4+40gbps+0.5m | ≈ EUR 15 | maker | full speed
44 | 1 | Cable | USB-A to USB-C, 10 Gb/s, 0.5 m |  |  |  | https://www.amazon.fr/s?k=cable+usb+a+usb+c+10gbps+0.5m | ≈ EUR 10 | maker | computers without USB-C
45 | 1 | Dock body | Éclair Dock, CNC aluminium, polished (cad/out/dock_body.step) |  |  |  | https://jlccnc.com | ≈ EUR 35 | maker (optional dock) | under-desk holder
46 | 1 | Dock clamp | cable clamp plate (cad/out/dock_clamp.step) |  |  |  | https://jlccnc.com | ≈ EUR 5 | maker (optional dock) | holds the USB4 plug in the dock
47 | 1 | Dock cable | USB-C to USB-C, USB4 40 Gb/s, 0.8 m |  |  |  | https://www.amazon.fr/s?k=cable+usb4+40gbps+0.8m | ≈ EUR 15 | maker (optional dock) | stays in the dock
48 | 2 | Wood screws | countersunk Ø4 × 16 |  |  |  | https://www.amazon.fr/s?k=vis+bois+tete+fraisee+4x16 | ≈ EUR 0.20 | maker (optional dock) | dock under the desk
49 | 4 | Clamp screws | M2 × 5 countersunk |  |  |  | https://www.amazon.fr/s?k=vis+m2+fraisee | ≈ EUR 0.20 | maker (optional dock) | clamp plate
TOTAL |  |  | One CARTOUCHE Éclair V1 256 GB, all parts + case + cables + box (batch of 10) |  |  |  | docs/COSTS.md | ≈ EUR 149.00 |  | per unit; prices at cost in docs/COSTS.md
TOTAL |  |  | Éclair V1 256 GB + Éclair Dock |  |  |  | docs/COSTS.md | ≈ EUR 206.50 |  | per unit, dock included

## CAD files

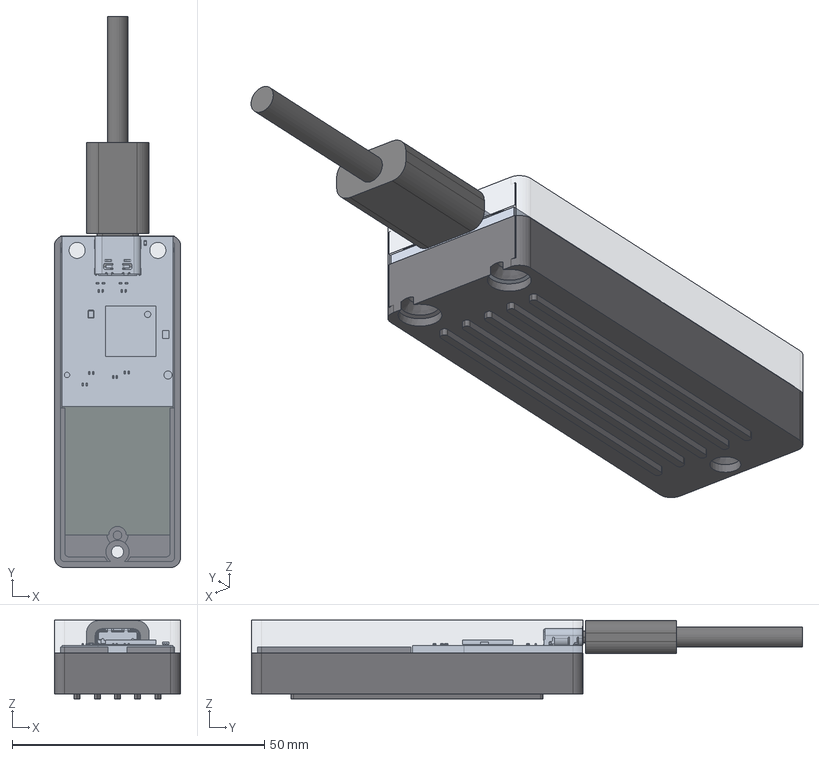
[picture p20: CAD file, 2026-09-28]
cad/out/eclair_v1_assembly.step
25.0 x 109.2 x 15.6 mm
board
ssd_2230
case_base
case_lid
usbc_plug

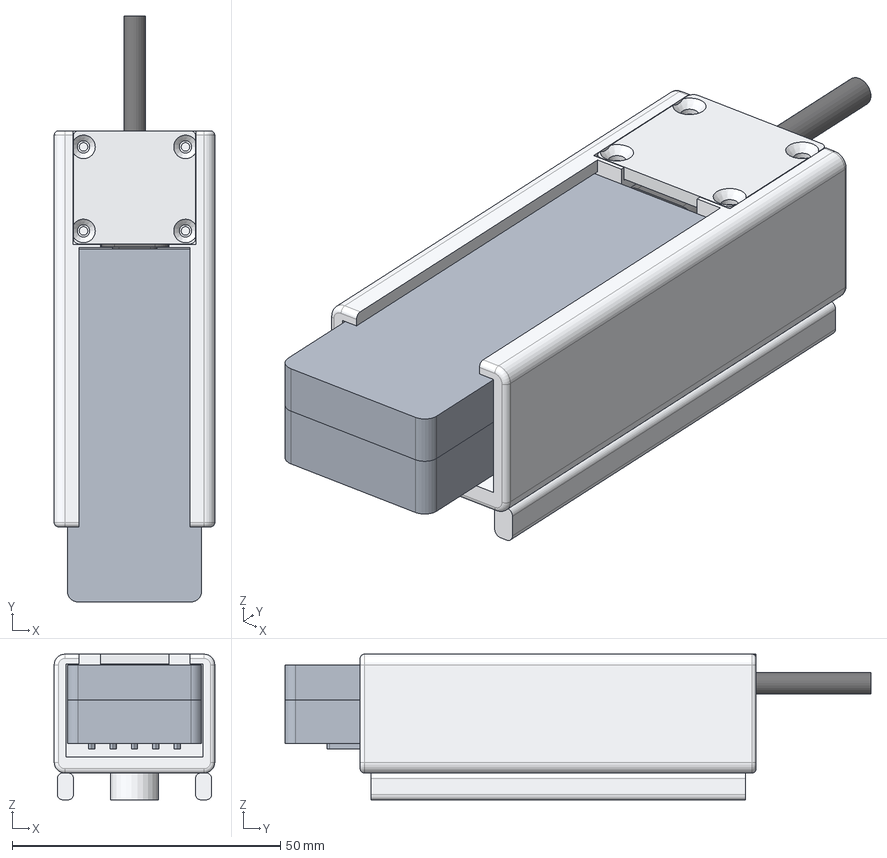
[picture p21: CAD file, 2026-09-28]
cad/out/eclair_dock_assembly.step
29.9 x 109.2 x 27.2 mm
board
ssd_2230
case_base
case_lid
usbc_plug
dock_body
dock_clamp

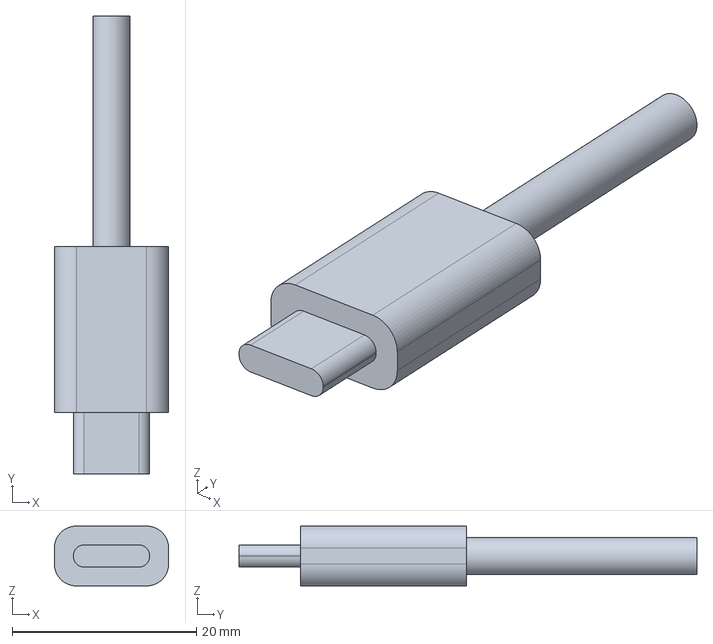
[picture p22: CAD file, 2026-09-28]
cad/out/usbc_plug.step
12.4 x 49.7 x 6.50 mm

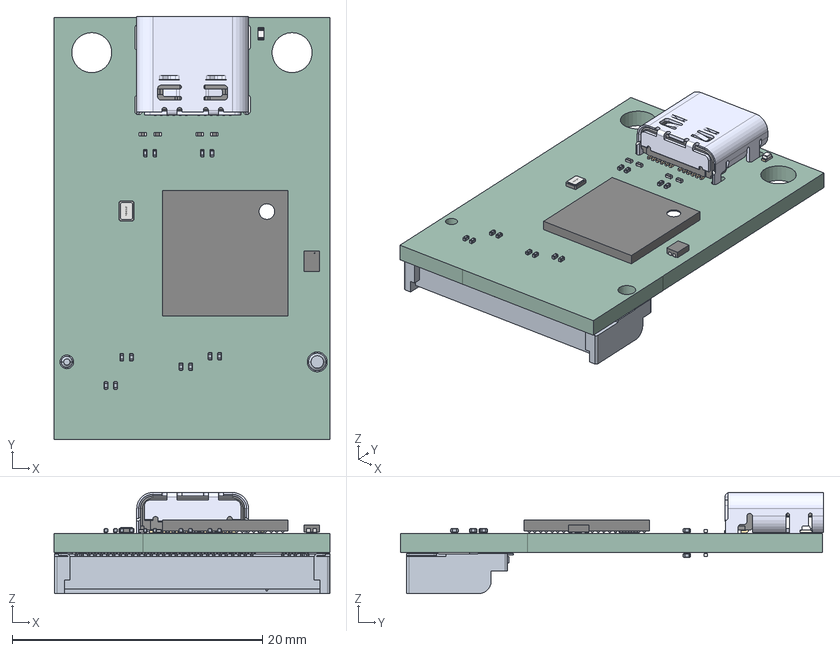
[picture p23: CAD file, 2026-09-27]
pcb/fab/cartouche-usb4.step
22.0 x 33.8 x 8.08 mm
kicad_embedded_7EEAD5C2A4050BCDB3B5FC61AF2BF601
cartouche-usb4 1.2.1 x 16
cartouche-usb4 1.2.2 x 16
Mid_Body x 8
Mark x 8
ball x 377
kicad_embedded_AA1570637F7BB2C88393162C90719726
Side Pad 2
Resin
Polarity Mark 1
Substrate
Side Pad 1
Bottom Pad 2
Polarity Mark 2
Bottom Pad 1
kicad_embedded_CE8E7E76D95C365B158B6CB7B1698585
kicad_embedded_A8FA8B1AF3948692580DA83B51A23DAC
cartouche-usb4_PCB

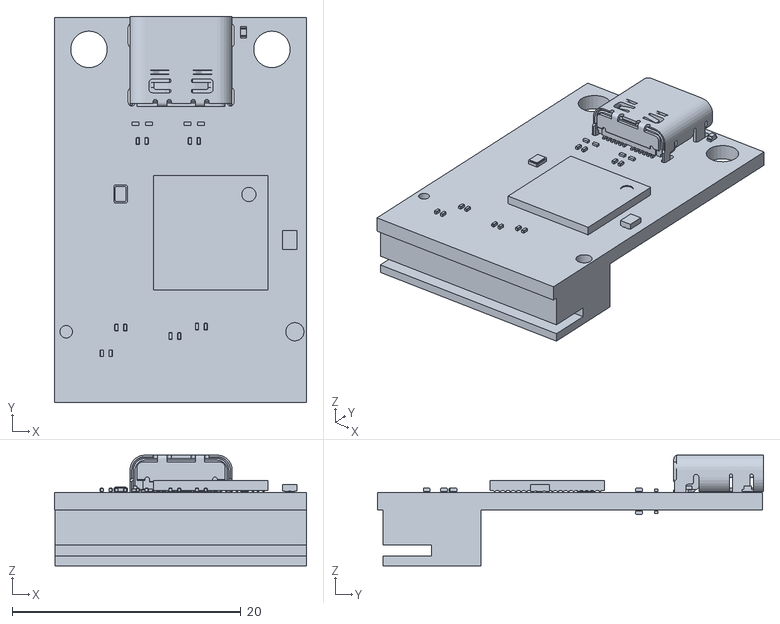
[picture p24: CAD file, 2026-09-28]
cad/out/board_mockup.stl
22.0 x 33.8 x 9.70

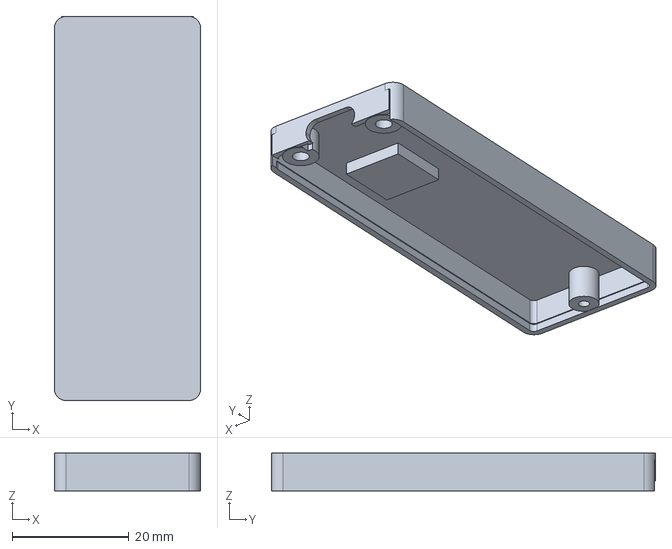
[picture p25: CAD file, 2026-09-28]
cad/out/case_lid.step
25.0 x 65.7 x 6.50 mm

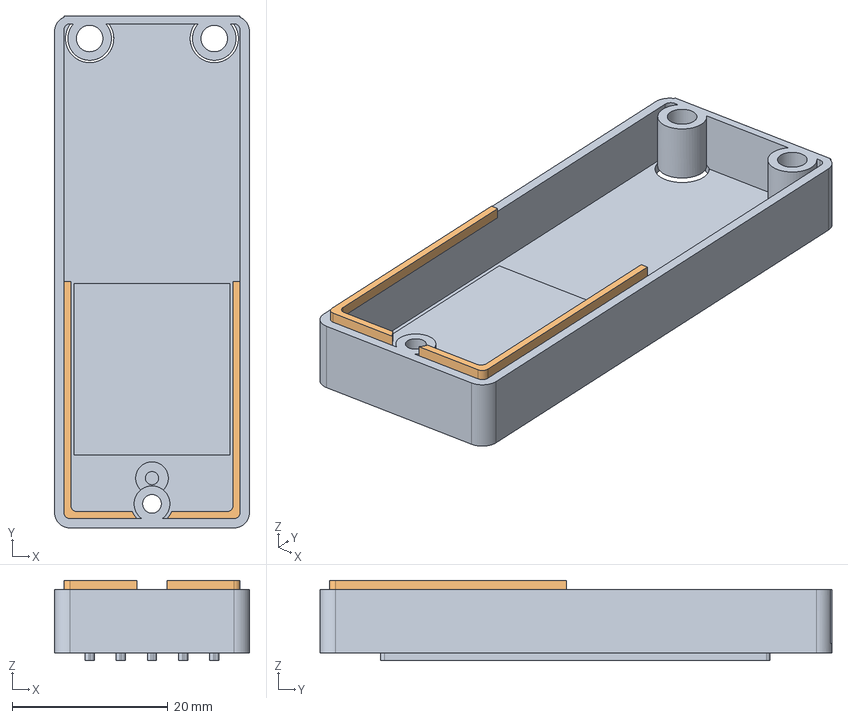
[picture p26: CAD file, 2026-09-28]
cad/out/case_base.step
25.0 x 65.7 x 10.3 mm

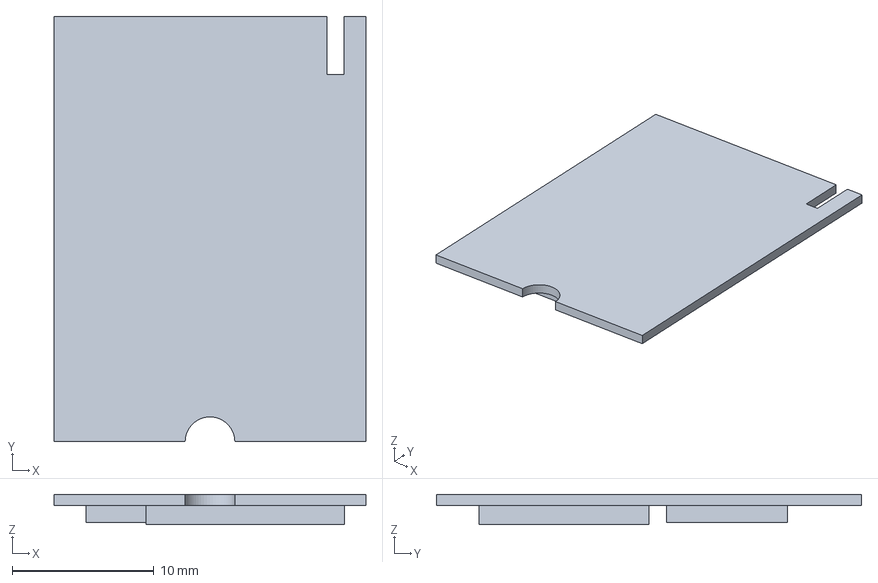
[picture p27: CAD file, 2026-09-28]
cad/out/ssd_2230.step
22.0 x 30.0 x 2.15 mm

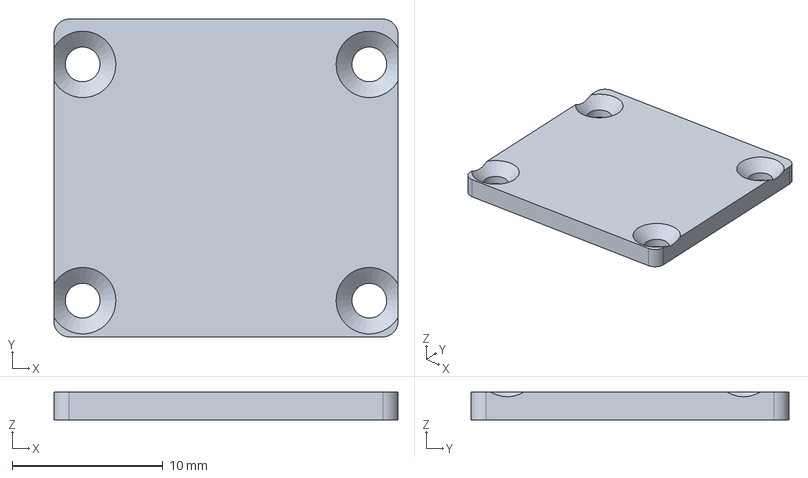
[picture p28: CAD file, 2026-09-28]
cad/out/dock_clamp.step
22.8 x 21.1 x 1.85 mm

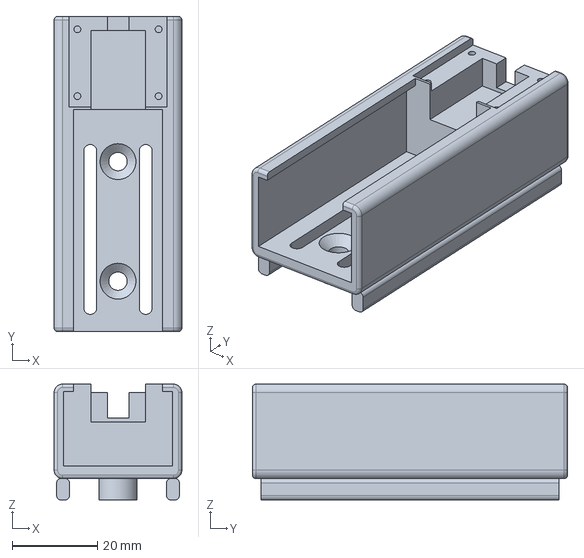
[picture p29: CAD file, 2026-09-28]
cad/out/dock_body.step
29.9 x 73.8 x 27.2 mm

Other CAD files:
cad/out/case_base.stl
cad/out/case_lid.stl
cad/out/dock_body.stl
cad/out/dock_clamp.stl
cad/out/ssd_2230.stl
cad/out/usbc_plug.stl

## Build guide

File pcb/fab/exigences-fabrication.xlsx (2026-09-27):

板材类型/Material Type | FR-4
板子层数/Layer Count | 4
板子厚度/Board Thickness | 1.6mm
外层铜厚/Outer Layer Copper Weight | 1oz
内层铜厚/Inner Layer Copper Weight | 1oz
阻抗/Impedance Control | 50/85
阻抗要求/Impedance Requirements
层 |  | 阻抗类型/Impedance type | 阻抗/Impedance | 线宽/Trace Width | 间距/Clearance
Layer | 1 | 差分/Differential Pair | 85Ohm | 4.36mil | 4mil
 |  | 单端/Single-ended | 50Ohm | 4.5mil | /
 | 2-3 | 差分/Differential Pair | 85Ohm | 3.69mil | 4mil
 |  | 单端/Single-ended | 50Ohm | 3.92mil | /
 | 4 | 差分/Differential Pair | 85Ohm | 4.36mil | 4mil
 |  | 单端/Single-ended | 50Ohm | 4.5mil | /

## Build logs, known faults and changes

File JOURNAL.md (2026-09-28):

---
title: "Cartouche USB"
author: "arthur.ellies"
description: "CARTOUCHE is a way to store heavy AI models and run them easily and fast, while keeping your data from going to third-party servers."
created_at: "2026-09-26"
---

# September 26: Website 1/3 — redesign, order configurator, accounts, payment

Creating animations on the website on Sandisk, Seagate and Eclair pages : https://cartouche.candygate.eu !

Changing the shop page to something better

Details from the git history (commit time → what changed):

- 12:29 first redesign: "object" look (paper, ink, Geist font), key in real-time 3D
- 12:43 simpler clean version (white, centred, static product renders)
- 13:44 professional version without images (Tailwind CSS, shadcn/ui style)
- 13:53 redone from zero: white, big typography, no images (the style kept today)
- 16:28 order configurator, CARTOUCHE accounts, developer program page, SEO
- 17:18 Supabase: developer form open, accounts behind a switch
- 17:31 payment: Stripe page created for each order (create-checkout), webhook on the order metadata
- 17:57 accounts opened (payments still closed)

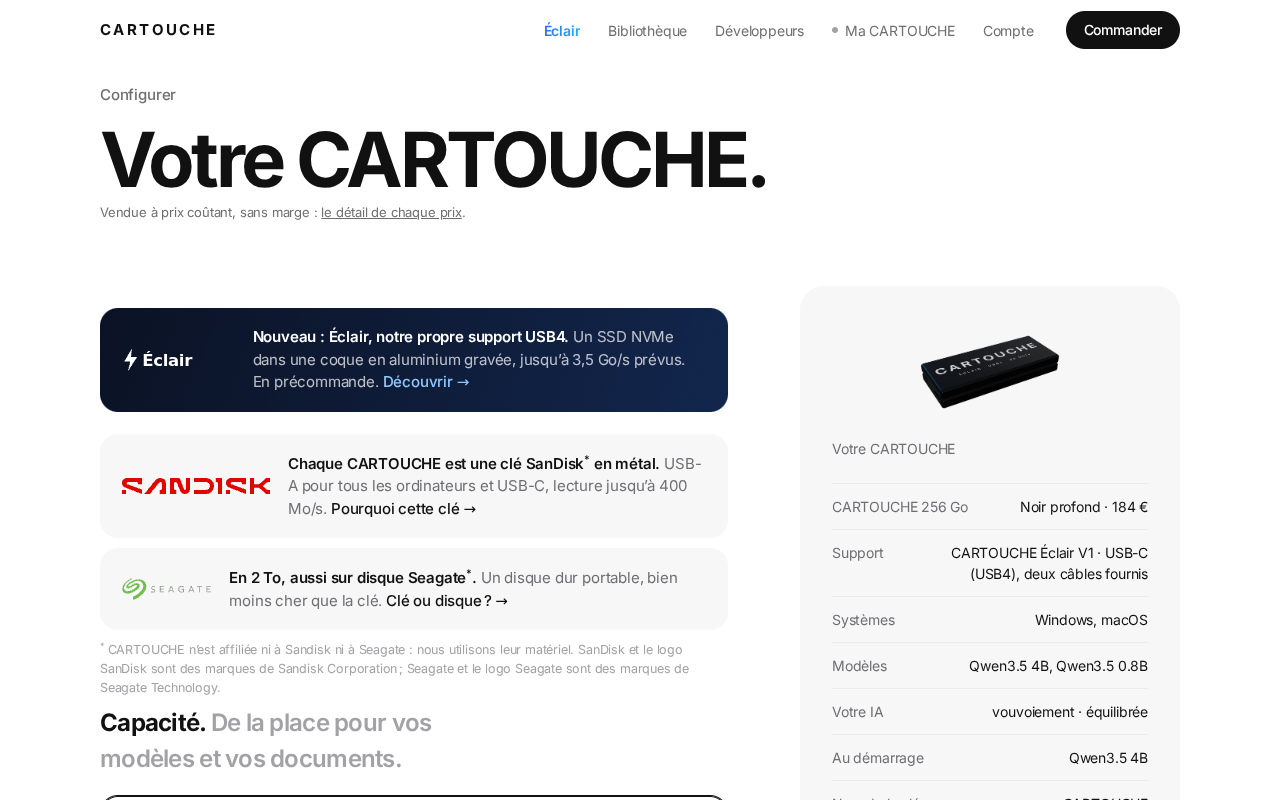
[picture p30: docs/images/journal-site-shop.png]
Shop configurator


**Total time spent: 4h30m**

# September 26: Website 2/3 — SanDisk shop, printed notice, Authenticity and FAQ pages

Details from the git history (commit time → what changed):

- 19:44 shop: CARTOUCHE on the metal SanDisk Ultra Dual Drive Luxe key (USB-A + USB-C), 64 GB to 1 TB, silver or gold
- 19:55 stock editable in stock.json, 512 GB out of stock, 2 TB added, SanDisk banner
- 20:01 preinstalled models up to half of the key
- 21:34 step-by-step scrolling in the shop (mouse wheel / trackpad)
- 21:47 printable A4 notice (4-panel fold, FR/EN), models shown as a grid in the shop
- 21:54 site → key connection working with Chrome/Edge "Local Network Access"
- 22:13 animated Authenticity page, official SanDisk logo with a non-affiliation note
- 22:25 full FAQ (43 questions, FAQ data for Google), Authenticity page in 12 animated steps
- 22:34 help shown when Edge silently blocks the connection to the key
- 22:38 Authenticity page: 20 sections (signing keys, verified models, revocation…)

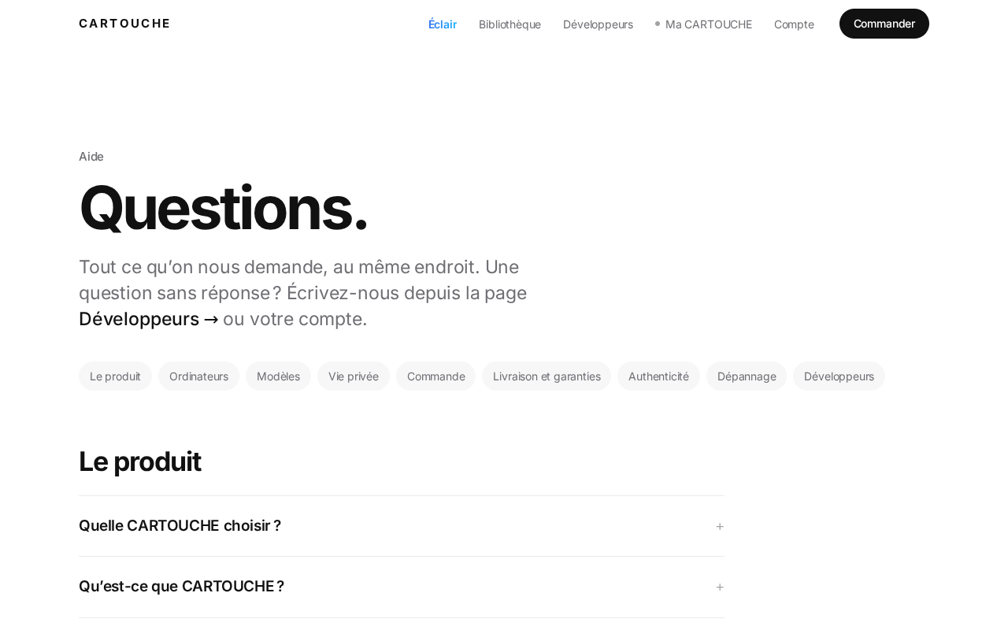
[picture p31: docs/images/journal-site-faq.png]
FAQ page


**Total time spent: 4h30m**

# September 26: Website 3/3 — "The key" page, personalisation, pre-orders, Seagate page

Details from the git history (commit time → what changed):

- 22:49 "The key" page: 20 animated sections (measured speed, load time, connectors, metal, comparison)
- 22:59 scroll-driven opening: giant SanDisk logo, metal key rising, rotating ring
- 23:18 shop: 5 personalisation steps (your AI, start-up model, settings, key name, gift)
- 23:25 real photo of the key in two layers (the rotating cover), cut out with free tools (rembg, Segment Anything)
- 23:43 "The key" and Authenticity sections fitted to the screen height (phones too)
- 23:56 animated Authenticity opening, fuller account page
- Sep 27, 09:40 free pre-orders, 2 TB option on a Seagate disk, key photo per colour, gift card
- Sep 27, 09:53 → 10:09 Seagate page: animated opening, then longer (the port, the cable plugging in, the laptop)

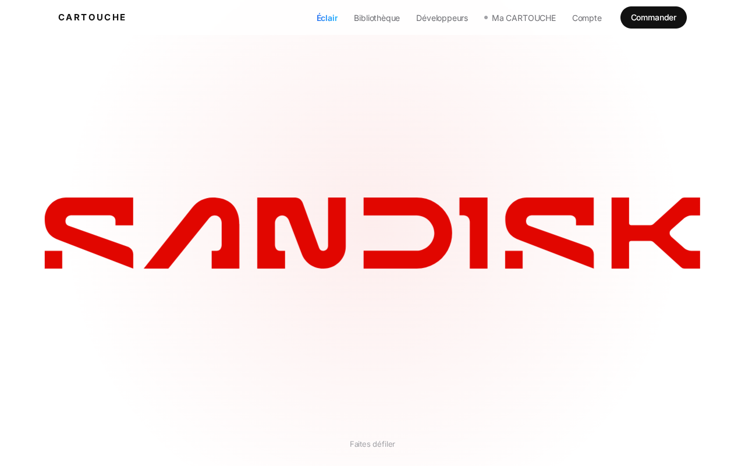
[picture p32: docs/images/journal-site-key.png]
The key page


**Total time spent: 4h48m**

# September 26: Choosing the components — USB4 + NVMe 2230

Goal: the fastest possible drive for CARTOUCHE, a local AI that loads multi-GB models from the drive at every start. Chose USB4 (40 Gb/s) with the ASMedia ASM2464PD bridge and an M.2 2230 NVMe SSD, single USB-C port. Instead of designing the high-speed part from scratch, found the open-source Leaves232 2230 USB4 enclosure (MIT), already built and tested by its author.

USB4 NVMe design

**Total time spent: 3h18m**

# September 26: Altium to KiCad 9 + first cartridge board

Converted the original Altium project to KiCad 9 with a script, then applied its fab rules (4 layers, 3.5 mil tracks, 0.2 mm vias, 85 ohm pairs). First version: a 30x64 mm game-cartridge board around the SSD, with an M2 screw slot and the CARTOUCHE name on the silkscreen. High-speed USB4/PCIe routing left untouched.

First cartridge board

**Total time spent: 1h**

# September 26: Fabrication settings and first NextPCB quote

Prepared the order: 4-layer FR-4 TG150, 1.6 mm, ENIG, controlled impedance for the 85 ohm differential pairs, 1 oz outer / 0.5 oz inner copper, assembly by the fab because the ASM2464PD is a 0.46 mm pitch BGA. Checked the ENIG gold thickness options and got a first quote (about $139 for the boards).

NextPCB settings

**Total time spent: 12m**

# September 27: v1.1 — The smallest board for an engraved enclosure

The drive will live in a closed case with the name engraved on it, so the big cartridge board made no sense. Went back to the smallest possible outline, 22.0 x 33.7 mm (the electronics fill it), no silkscreen, the case holds the SSD. Planned SSD: 256 GB or 1 TB. Exported new Gerbers, drills, pick-and-place and a STEP model to design the case, and published everything on GitHub.

v1.1 board

**Total time spent: 5h**

# September 27: Small USB4 NVMe board — KiCad port and fabrication files

Took the open-source Leaves232 USB4 2230 enclosure (ASM2464PD, MIT) and made it the CARTOUCHE drive. Converted the Altium project to KiCad 9 with scripts, tried a 30×64 mm cartridge board first, then went back to the smallest possible 22×34 mm board since it will live in an engraved case that also holds the SSD. Generated Gerbers, drill files, pick-and-place, and a STEP model to design the case. Kept the USB4/PCIe routing untouched since it's proven.
Next: order 5 boards, design the aluminium case, measure real load times.

Project image

**Total time spent: 3h**

# September 27: Cost verification from the real BOM quote

Worked out what one board costs. From the original design's real Huaqiu BOM quote: 65.71 CNY (about 8.5 €) of components per board, without the ASM2464PD bridge, which has no public price and must be quoted by the assembler. The old $139 PCB quote was for the 30x64 mm board, so it needs redoing for the new 22x34 mm one. The SSD just plugs in by hand. Noted that a 10 Gb/s USB-A cable caps it at about 1 GB/s; full USB4 needs a 40 Gb/s USB-C cable.

Component cost breakdown

**Total time spent: 12m**

# September 27: 3D web animation of the KiCad board model

Exported the board's full 3D model from KiCad (GLB with copper tracks, 19 MB compressed to 1.8 MB with meshopt) and built a scroll-driven 3D film for the product page with three.js: the real board turns around to show both sides, the M.2 SSD plugs in, an aluminium case closes around it and a laser engraves the name. It shows people exactly what they pre-order, and made us think through the case: two aluminium halves, USB-C opening, engraved top.

Project 3D model

**Total time spent: 1h**

# September 27: Enclosure colors, capacities, and component layout

Extended the 3D product film with a tour of the real board: labels pinned to the actual components from the KiCad model (USB-C, ASM2464PD, 25 MHz crystal, SSD power switch, M.2 connector), a flip to the bottom side, then the SSD, the case and a two-pass laser engraving. Picked the case finishes (black, blue-grey, violet anodised aluminium) and capacities: 256 GB, 1 TB and 2 TB. 2 TB is the limit: no bigger 2230 SSD exists and the 3.3 V supply couldn't power one.

Enclosure and board

**Total time spent: 24m**

# September 27: Cables and additional parts to purchase

Chose the cables: a USB-C 40 Gb/s USB4 cable (about 15 €) for full speed on USB4/Thunderbolt ports, plus a 10 Gb/s USB-A cable (10 €) so it works on any computer. Both go in the box. Listed what the assembler buys (every BOM part; the ASM2464PD must be confirmed, JLCPCB stocks it as C7509569) and what I buy myself: the M.2 2230 SSD, the CNC case, thermal pads (10x10 mm on the chip), three M2x3 screws and packaging. Updated the per-capacity costs.

Project image

**Total time spent: 12m**

# September 27: Total cost per unit — from chip to shipping

Worked out what one finished drive costs, per capacity. Real prices: parts 8.50 € (BOM quote), ASM2464PD $26.60 (Alibaba), cable 10 €, Colissimo shipping 5.49 €. Estimates to confirm: PCB and assembly, CNC anodised aluminium case, box. A batch of 10 costs about 140 € (256 GB) to 240 € (2 TB) per drive, and a batch of 100 about 102 € to 202 €. Next: re-quote the smaller board at NextPCB and draw the case from the STEP model.

Component cost breakdown

**Total time spent: 24m**

# September 27: Brainstorming

looking for the best SSD compatible
i learnt that we can't use more than 2To for this card because of the power supply
to go to a 24To key we will need to design all the card from 0 again!

Project image

**Total time spent: 1h12m**

# September 27: Thinking about our fellow developers

I think it's important to support the developers and teenagers who will be interested, and I'm not especially trying to make a profit on this project.

Project image

**Total time spent: 2h**

# September 28: One error patched

When I printed the parts, they didn't fit, so after some research I realised it simply wasn't the right components. The mock-up just didn't have a slot, and the SSD was too low. I'm going to reprint everything to test the layout and the screws.

Section of the assembly

**Total time spent: 1h18m**

# September 28: The board runs too hot

I was thinking that a board that can handle up to 40 Gb/s would get very hot during long sessions, and since this case is meant to stay plugged in, hung under a desk, all day long, I had to avoid setting that desk on fire :)

I think this is the best option: my other idea was to add a fan, but that would make the case much more fragile and noisy, and I'd also have to add vents to the case. We'll try it on the prototype, and if it gets too hot, we'll rethink the system.

I updated the website with new animations so customers can understand.

This project is aimed at young devs at my high school: I talked about it with the principal and with some students who would be very interested in buying one at cost.

Cooling: heat path inside the case (section, to scale)

Airflow direction under the desk (cross-section, to scale)

Expected temperatures before / after the cooling changes (estimate)

**Total time spent: 2h**

# September 28: Offering an ecosystem

Personally, I plan to use this drive myself. Actually, it's not really a USB key anymore. I plan to use it as a case plugged in under the desk, plugged in all day. My PC is on all day, and I can easily come and change the drive, change the cartridge, put in a code model or an image generation model depending on what I need. And that way I don't have to struggle with the cable: I just take it, pull it out, it's easy.

From what I understood, the air heats up around the small fins, rises through the slots in the plate and leaves through the 5 mm gap at both ends of the dock. There is no fan: it's passive cooling, a bit like a MacBook Air.

I think it's a big and very important change, because it will save people time while offering a product that also gets rid of the heat a bit better, so it's a really nice improvement.

Dock, desk side: rails, screw bosses and air slots

Airflow under the desk

Éclair sliding into the dock

**Total time spent: 4h**

# September 28: Active cooling on the web

I made four pages about the dock to better explain how it works. The animations make it easy to really see how it works.

Details from the git history (commit time → what changed):

- 17:33 first 3D section for the dock on the Éclair page
- 17:59 a dedicated long 3D page for the dock (exploded parts, desk side, screws, cable, slide-in, x-ray, colours, airflow, dimensions)
- 18:07 the film made about 5× longer (machining from a block, polish, clearance close-up, plug seating, load timer)
- 18:11 soft shadows, oak desk, fluted end mill, cable along the desk, phone framing
- 19:00 four pages on a shared 3D engine: the object, the installation (1:1 drilling template PDF, drill, screws, cable to the PC), everyday use (three Éclair, laptop), the heat (heat map from the estimate, section, pads, fins, blocked air vs 5 mm gap)
- 21:57 bug fixes: mirrored template, the "it goes with you" sequence

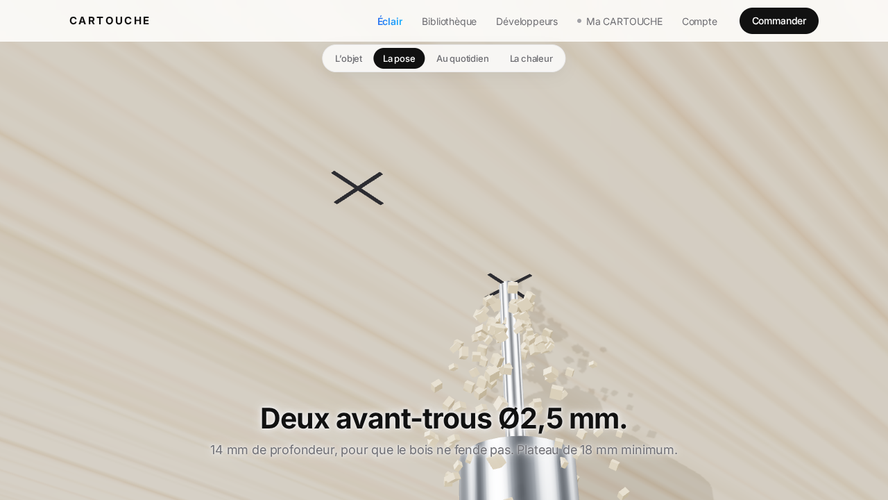
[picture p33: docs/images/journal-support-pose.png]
Installation page: drilling


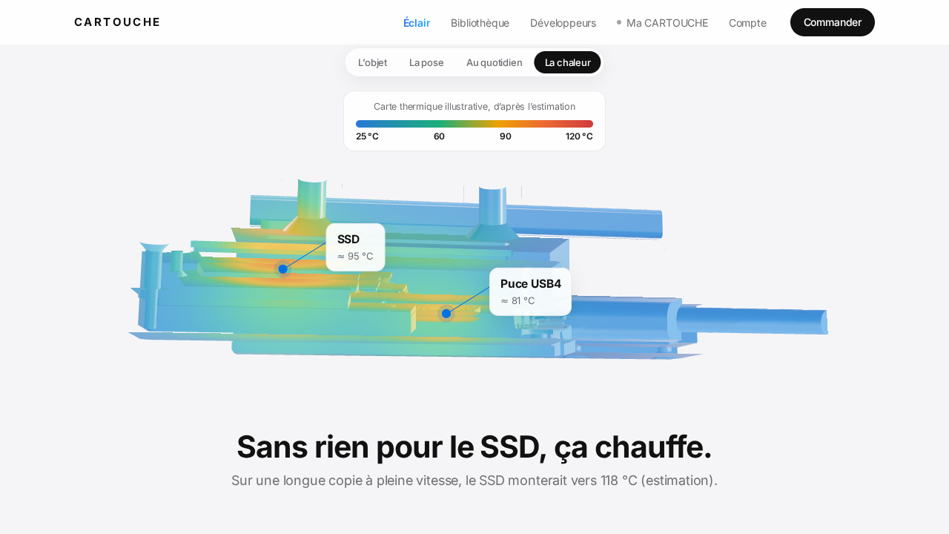
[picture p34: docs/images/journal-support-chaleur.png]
Heat page: heat map in section


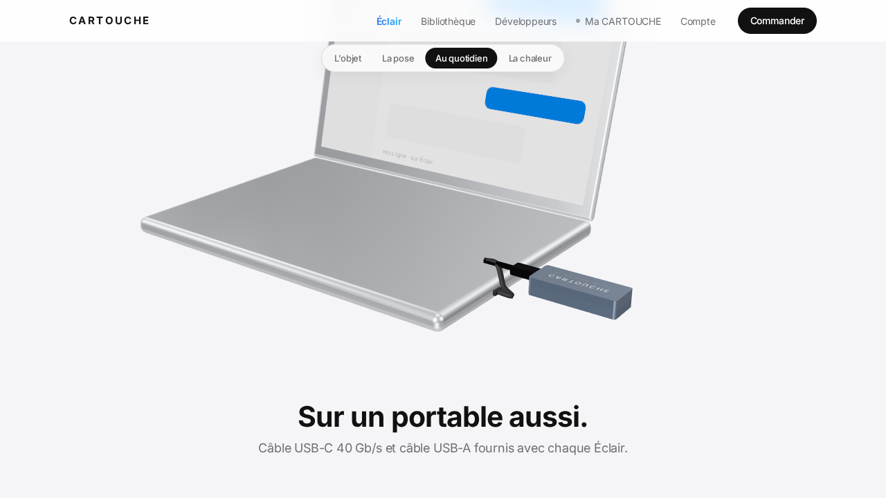
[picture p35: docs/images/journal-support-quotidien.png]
Everyday page: on a laptop


**Total time spent: 3h30m**

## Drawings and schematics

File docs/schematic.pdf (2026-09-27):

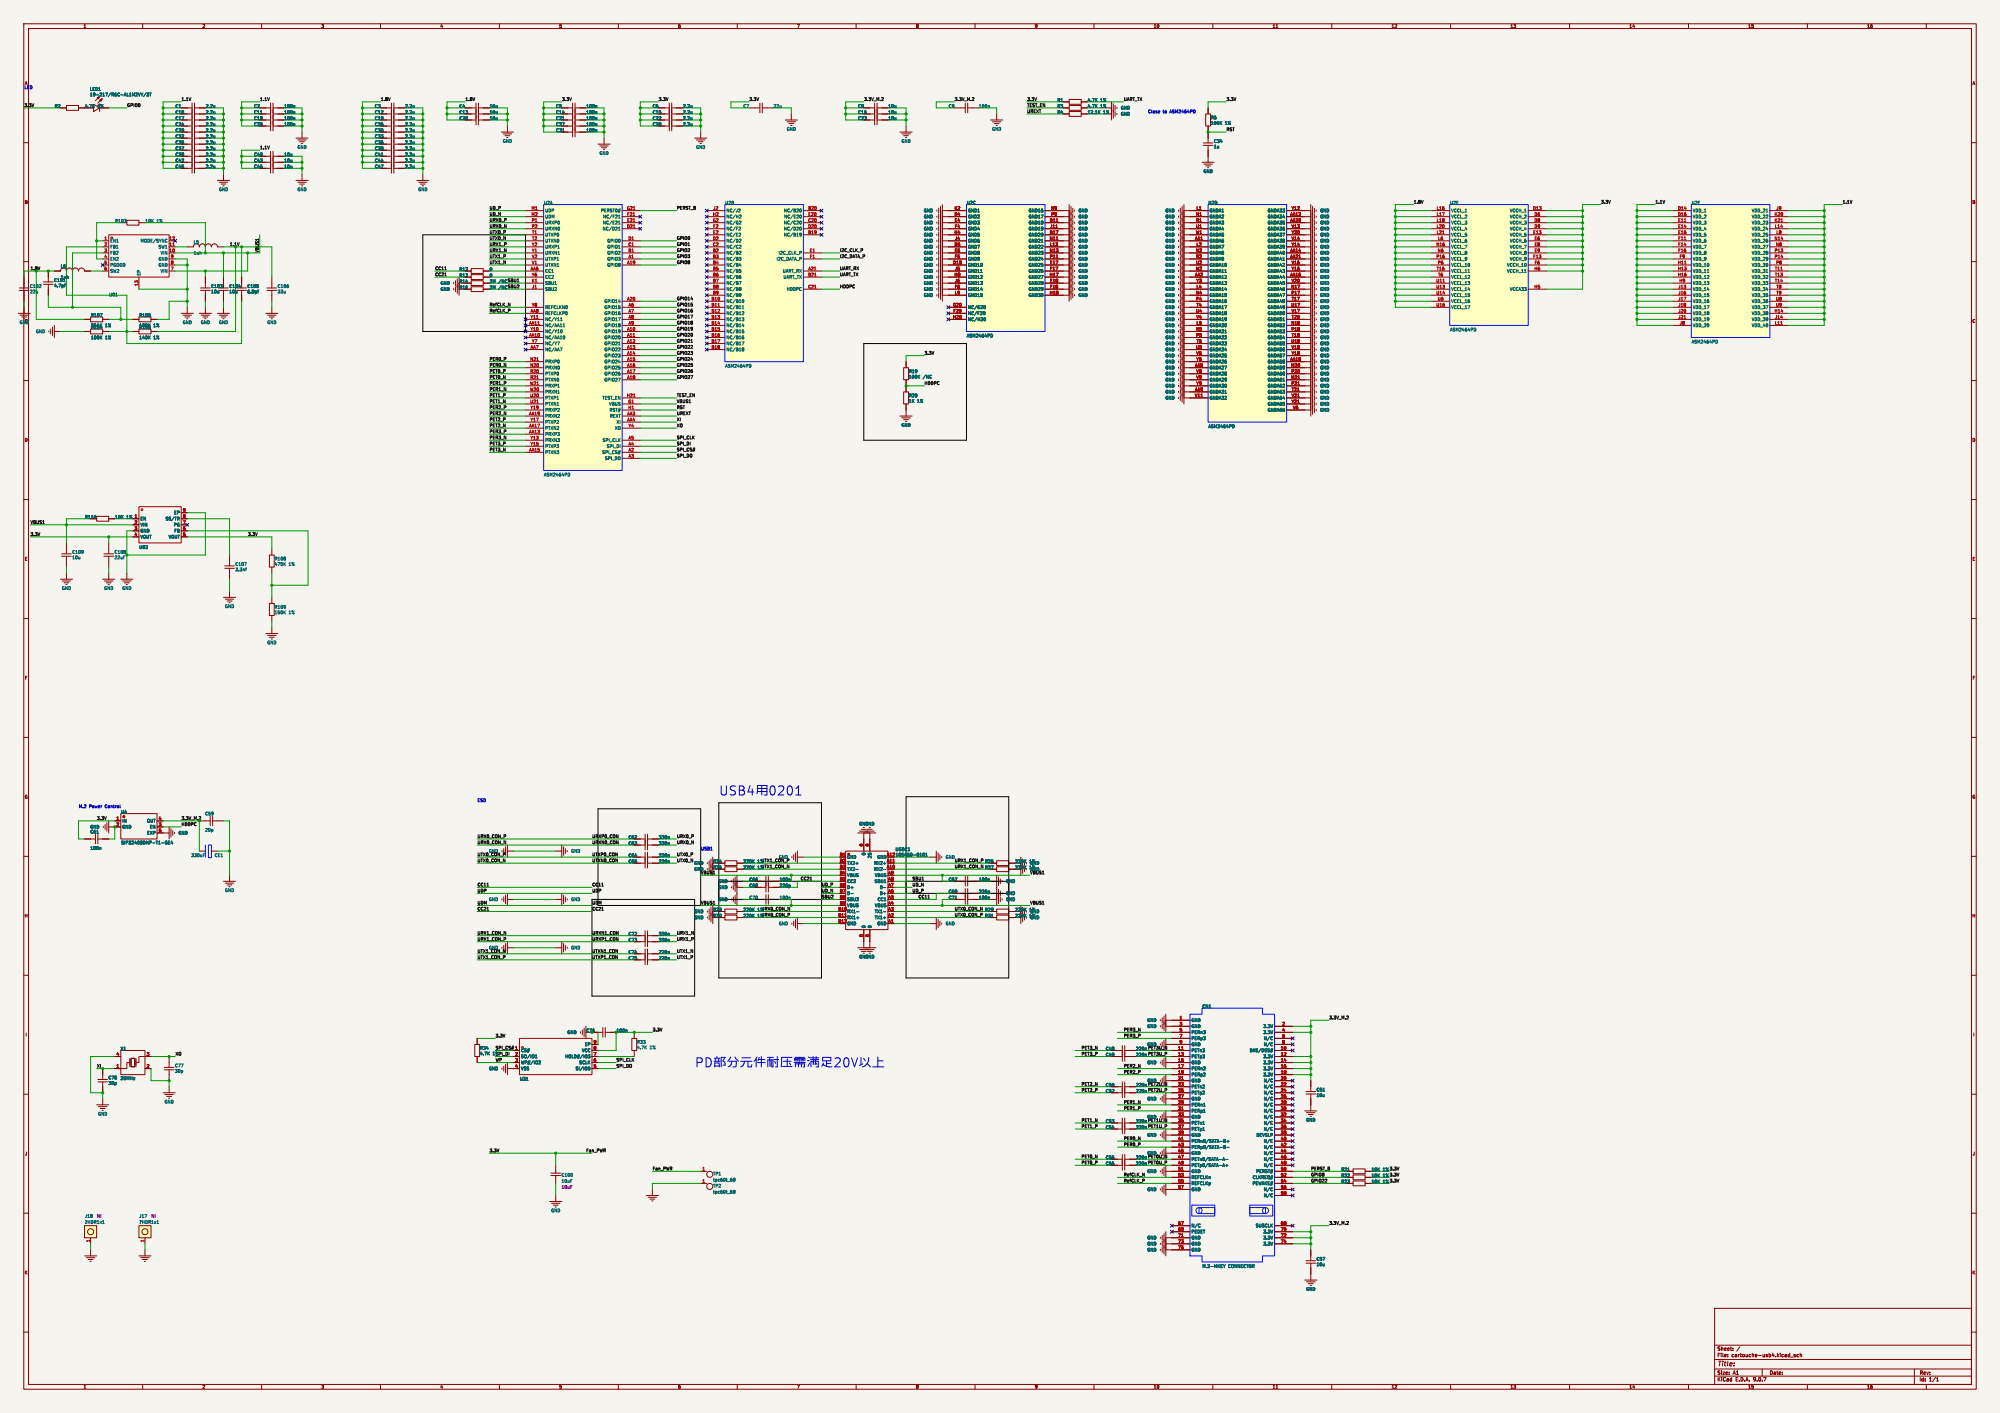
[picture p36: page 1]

GND GND GND GND GND

GND GND GND GND GND GND GND GND GND GND GND GND GND GND GND GND GND GND GND GND GND GND GND GND GND GND GND GND GND GND GND GND GND GND GND GND GND GND GND GND GND GND GND GND GND GND GND GND

GND GND

GND
GND GND GND

74 GND GND GND GND GND GND GND GND GND GND GND GND GND GND

þÿPD•èRQCNö€S‹—ná•³20VNåN

Id: 1/1 Title: File: cartouche-usb4.kicad_sch Sheet: /

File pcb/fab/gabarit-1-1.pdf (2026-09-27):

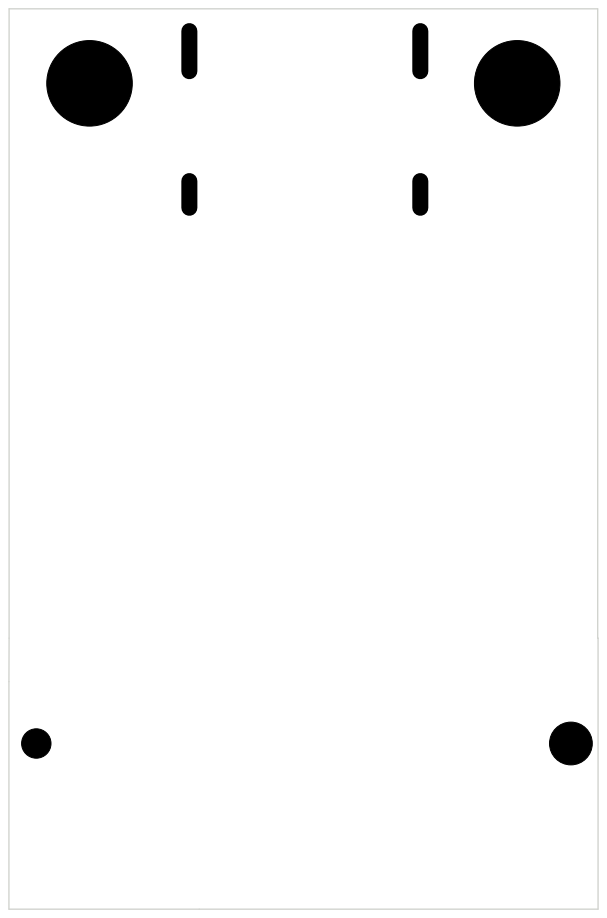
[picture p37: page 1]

Id: 1/1 Title: File: cartouche-usb4.kicad_pcb Sheet:

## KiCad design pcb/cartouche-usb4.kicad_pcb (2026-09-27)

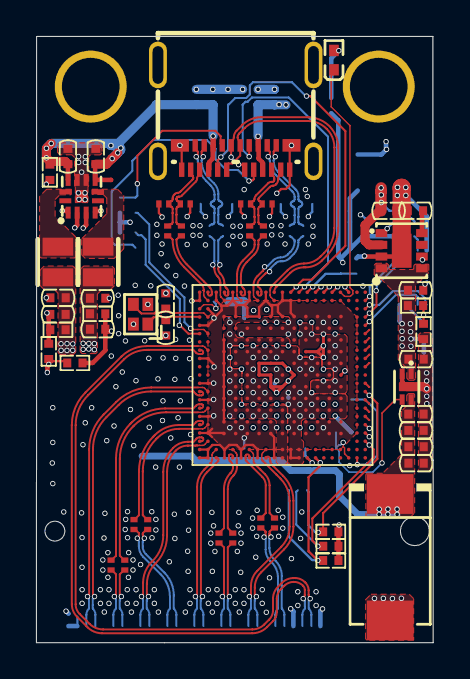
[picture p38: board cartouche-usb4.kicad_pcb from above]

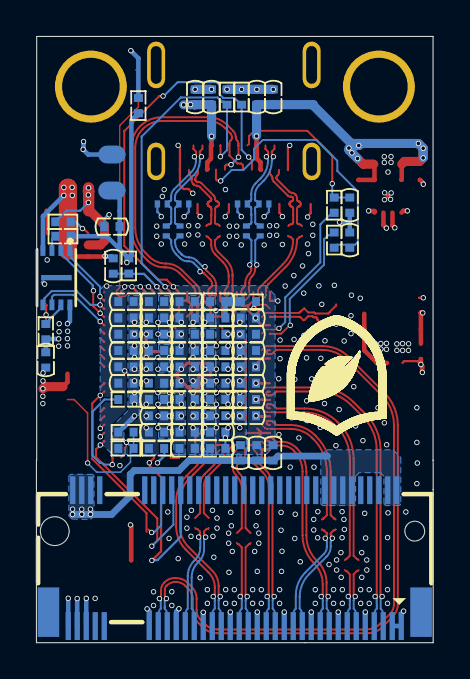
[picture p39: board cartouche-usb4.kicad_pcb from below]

Board: 4 copper layers, 22.0 x 33.7 mm, 134 parts (80 on the bottom side), 82 nets.

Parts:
C1, C3, C6, C10, C12, C15, C17, C19, C22, C24, C26, C28, C29, C30, C32, C33, C35, C36, C37, C38, C39, C41, C42, C44, C45, C47: 2.2u; C0402
C2, C5, C9, C11, C14, C18, C21, C25, C27, C31, C61, C66, C67, C70, C71, C76: 100n; C0402
C4, C8, C13, C16, C20, C23, C40, C43, C46, C51, C57, C103, C104, C109: 10u; C0402
C7, C102: 22u; C0402
C34: 1u; C0402
C48, C49, C50, C52, C53, C54, C55, C56, C64, C65, C74, C75: 220n; C0201
C59: 20p; C0402
C62, C63, C72, C73: 330n; C0201
C68, C69: 220p; C0402
C77, C78: 30p; C0402
C100: 10uF; C0402
C101: 4.7pf; C0402
C105: 6.8pf; C0402
C106: 33u; C0402
C107: 3.3nf; C0402
C108: 22uf; C0402
CE1: 330uF; CAP-SMD_L7.3-W4.3-R-RD
CN1: M.2-MKEY CONNECTOR; CONN-SMD_APCI0113-P001A
J17, J18: ?HDR1x1; Header
L5, L6: 1uh; IND-SMD_L2.0-W1.6-B
LED1: 19-217/R6C-AL1M2VY/3T; LED0402-RD
R1, R2, R3, R33, R34: 4.7K 1%; R0402
R4: 12.1K 1%; R0402
R6, R104, R106: 100K 1%; R0402
R12, R13: 0; R0402
R14, R16: 2M /NC; R0402
R19: 100K /NC; R0402
R20: 1K 1%; R0402
R21, R22, R23, R103, R110: 10K 1%; R0402
R24, R25, R26, R27, R28, R29, R30, R31: 220K 1%; R0201
R105: 140K 1%; R0402
R107: 261K 1%; R0402
R108: 475K 1%; R0402
R109: 150K 1%; R0402
TP1, TP2: tpc60t_68
U01: LTC3315AEV#TRPBF; LQFN-12_L2.0-W2.0-P0.50-TL-EP0.7
U2: ASM2464PD; BGA273C46P21X21_1000X1000X98
U02: TPS82130SILR; USIP-8_L3.0-W2.8-P0.65-TL-EP
U4: SIP32408DNP-T1-GE4
U31: ZD25WQ16CEIGR; USON-8_L3.0-W2.0-P0.50-BL-EP
USBC1: 105450-0101; USB-C-SMD_TYPE-C-USB-18
X1: 25MHz; CRYSTAL-SMD_4P-L1.6-W1.2-BL

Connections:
1.1V: C1.1, C2.1, C10.1, C11.1, C17.1, C18.1, C24.1, C25.1, C29.1, C32.1, C35.1, C37.1, C39.1, C40.1, C42.1, C43.1, C45.1, C46.1, C105.2, C106.2, L5.2, R105.1, U2.D14, U2.D16, U2.E11, U2.E14, U2.E16, U2.F9, U2.F11, U2.F14, U2.F16, U2.H9, U2.H11, U2.H13, U2.H14, U2.H16, U2.J8, U2.J9, U2.J13, U2.J14, U2.J16, U2.J17, U2.J18, U2.J20, U2.J21, U2.K20, U2.K21, U2.L8, U2.L11, U2.L14, U2.N8, U2.N14, U2.P8, U2.P13, U2.P14, U2.T8, U2.T9, U2.T11, U2.T13, U2.T14, U2.U8, U2.U9
1.8V: C3.1, C4.1, C12.1, C13.1, C19.1, C20.1, C26.1, C30.1, C33.1, C36.1, C38.1, C41.1, C44.1, C47.1, C101.2, C102.2, L6.1, R107.2, U2.L6, U2.L16, U2.L17, U2.L18, U2.L20, U2.L21, U2.N6, U2.N16, U2.P6, U2.P16, U2.T6, U2.T16, U2.U6, U2.U11, U2.U13, U2.U14, U2.U16
3.3V: C5.1, C6.1, C7.1, C14.1, C15.1, C21.1, C22.1, C27.1, C28.1, C31.1, C61.1, C76.2, C100.1, C108.2, R1.1, R2.1, R6.2, R19.2, R21.2, R22.2, R23.2, R33.1, R34.1, R108.1, TP1.1, U02.4, U02.5, U2.D6, U2.D8, U2.D9, U2.D13, U2.E6, U2.E8, U2.E9, U2.E13, U2.F6, U2.F13, U2.H5, U2.H6, U4.1, U31.8
3.3V_M.2: C8.1, C9.1, C16.1, C23.1, C51.1, C57.1, C59.1, CE1.1, CN1.2, CN1.4, CN1.12, CN1.14, CN1.16, CN1.18, CN1.70, CN1.72, CN1.74, U4.4
CC11: C69.1, R12.1, USBC1.A5
CC21: C68.2, R13.1, USBC1.B5
GND: C1.2, C2.2, C3.2, C4.2, C5.2, C6.2, C7.2, C8.2, C9.2, C10.2, C11.2, C12.2, C13.2, C14.2, C15.2, C16.2, C17.2, C18.2, C19.2, C20.2, C21.2, C22.2, C23.2, C24.2, C25.2, C26.2, C27.2, C28.2, C29.2, C30.2, C31.2, C32.2, C33.2, C34.1, C35.2, C36.2, C37.2, C38.2, C39.2, C40.2, C41.2, C42.2, C43.2, C44.2, C45.2, C46.2, C47.2, C51.2, C57.2, C59.2, C61.2, C66.1, C67.2, C68.1, C69.2, C70.1, C71.2, C76.1, C77.2, C78.2, C100.2, C102.1, C103.1, C104.1, C106.1, C107.1, C108.1, C109.1, CE1.2, CN1.1, CN1.3, CN1.9, CN1.15, CN1.21, CN1.27, CN1.33, CN1.39, CN1.45, CN1.51, CN1.57, CN1.71, CN1.73, CN1.75, J17.1, J18.1, R3.2, R4.2, R14.1, R16.1, R20.1, R24.1, R25.2, R26.1, R27.2, R28.1, R29.2, R30.1, R31.2, R104.2, R106.1, R109.2, TP2.1, U01.8, U01.9, U01.13, U02.3, U02.9, U2.AA1, U2.AA2, U2.AA5, U2.AA9, U2.AA12, U2.AA14, U2.AA16, U2.AA18, U2.AA20, U2.AA21, U2.D4, U2.D5, U2.D11, U2.D17, U2.D18, U2.E4, U2.E5, U2.E17, U2.E18, U2.F4, U2.F5, U2.F8, U2.F17, U2.F18, U2.H4, U2.H8, U2.H17, U2.H18, U2.J4, U2.J5, U2.J6, U2.J11, U2.K2, U2.L1, U2.L2, U2.L4, U2.L5, U2.L9, U2.L13, U2.M20, U2.M21, U2.N1, U2.N2, U2.N4, U2.N5, U2.N9, U2.N11, U2.N13, U2.N17, U2.N18, U2.P4, U2.P5, U2.P9, U2.P11, U2.P17, U2.P18, U2.P20, U2.P21, U2.R1, U2.R2, U2.T4, U2.T5, U2.T17, U2.T18, U2.T20, U2.T21, U2.U1, U2.U2, U2.U4, U2.U5, U2.U17, U2.U18, U2.V4, U2.V5, U2.V6, U2.V8, U2.V9, U2.V11, U2.V13, U2.V14, U2.V16, U2.V17, U2.V18, U2.V20, U2.V21, U2.W1, U2.W2, U2.Y3, U2.Y5, U2.Y9, U2.Y12, U2.Y14, U2.Y16, U2.Y18, U2.Y20, U2.Y21, U4.2, U4.5, U31.4, U31.9, USBC1.0, USBC1.A1, USBC1.A12, USBC1.B1, USBC1.B12, X1.2, X1.4
GPIO0: LED1.2, U2.D1
GPIO8: CN1.52, R22.1, U2.A19
GPIO22: CN1.54, R23.1, U2.A13
HDDPC: R19.1, R20.2, U2.C21, U4.3
NetC101_1: C101.1, R106.2, R107.1, U01.3
NetC105_1: C105.1, R104.1, R105.2, U01.2
NetC107_2: C107.2, U02.8
NetL5_1: L5.1, U01.11
NetL6_2: L6.2, U01.6
NetLED1_1: LED1.1, R2.2
NetR12_2: R12.2, U2.AA6
NetR13_2: R13.2, U2.Y6
NetR33_2: R33.2, U31.7
NetR103_1: R103.1, U01.1, U01.4
NetR108_2: R108.2, R109.1, U02.6
NetR110_2: R110.2, U02.1
PER0_N: CN1.41, U2.N20
PER0_P: CN1.43, U2.N21
PER1_N: CN1.29, U2.W20
PER1_P: CN1.31, U2.W21
PER2_N: CN1.17, U2.AA19
PER2_P: CN1.19, U2.Y19
PER3_N: CN1.5, U2.Y13
PER3_P: CN1.7, U2.AA13
PERST_B: CN1.50, R21.1, U2.G21
PET0U_N: C55.2, CN1.47
PET0U_P: C56.2, CN1.49
PET0_N: C55.1, U2.R21
PET0_P: C56.1, U2.R20
PET1U_N: C53.2, CN1.35
PET1U_P: C54.2, CN1.37
PET1_N: C53.1, U2.U21
PET1_P: C54.1, U2.U20
PET2U_N: C50.2, CN1.23
PET2U_P: C52.2, CN1.25
PET2_N: C50.1, U2.AA17
PET2_P: C52.1, U2.Y17
PET3U_N: C48.2, CN1.11
PET3U_P: C49.2, CN1.13
PET3_N: C48.1, U2.AA15
PET3_P: C49.1, U2.Y15
RST: C34.2, R6.1, U2.H1
RefCLK_N: CN1.53, U2.Y8
RefCLK_P: CN1.55, U2.AA8
SBU1: R14.2, U2.K1, USBC1.A8
SBU2: R16.2, U2.J1, USBC1.B8
SPI_CLK: U2.A5, U31.6
SPI_CS#: U2.A2, U31.1
SPI_DI: U2.A4, U31.2
SPI_DO: U2.A3, U31.5
TEST_EN: R3.1, U2.H21
UART_TX: R1.2, U2.B21
UD_N: U2.M2, USBC1.A7, USBC1.B7
UD_P: U2.M1, USBC1.A6, USBC1.B6
UREXT: R4.1, U2.AA3
URX0_CON_N: C63.1, R28.2, USBC1.B10
URX0_CON_P: C62.1, R30.2, USBC1.B11
URX0_N: C63.2, U2.P2
URX0_P: C62.2, U2.P1
URX1_CON_N: C72.1, R27.1, USBC1.A10
URX1_CON_P: C73.1, R25.1, USBC1.A11
URX1_N: C72.2, U2.Y1
URX1_P: C73.2, U2.Y2
UTX0_CON_N: C65.1, R29.1, USBC1.A3
UTX0_CON_P: C64.1, R31.1, USBC1.A2
UTX0_N: C65.2, U2.T2
UTX0_P: C64.2, U2.T1
UTX1_CON_N: C74.1, R26.2, USBC1.B3
UTX1_CON_P: C75.1, R24.2, USBC1.B2
UTX1_N: C74.2, U2.V1
UTX1_P: C75.2, U2.V2
VBUS1: C66.2, C67.1, C70.2, C71.1, C103.2, C104.2, C109.2, R103.2, R110.1, U01.7, U01.10, U02.2, U2.G1, USBC1.A4, USBC1.A9, USBC1.B4, USBC1.B9
WP: R34.2, U31.3
XI: C78.1, U2.AA4, X1.1
XO: C77.1, U2.Y4, X1.3

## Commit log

2026-09-27 CARTOUCHE USB4: cartridge-shaped USB4 NVMe 2230 board (KiCad 9, Gerbers, BOM)
    [cartouche-usb4-Bottom Layer.gbl, cartouche-usb4-Bottom Overlay.gbo, cartouche-usb4-Bottom Paste.gbp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]
2026-09-27 v1.1: smallest possible board (22.0 x 33.7 mm) for a closed case
    The name is engraved on the case, not printed on the board; the case holds the
    SSD. Keeps the original proven outline. Adds a STEP model to design the case,
    Gerbers with separate plated/non-plated drills, updated renders and README.
    [cartouche-usb4-Bottom Layer.gbl, cartouche-usb4-Bottom Overlay.gbo, cartouche-usb4-Bottom Paste.gbp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]
2026-09-27 Cost estimate from the real BOM quote
2026-09-27 Full cost per capacity: board, case, cable, packaging, shipping, fees
2026-09-27 Costs: two cables in the box (USB-C 40 Gb/s + USB-A), purchase list besides the assembled board
2026-09-27 Éclair V1: case CAD (CadQuery source, STEP/STL), SSD 2230 and USB-C plug models, full assembly STEP with electronics, BOM.csv, wiring diagram, firmware docs and check tool, folders
    [BOM.csv, board_mockup.stl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]
2026-09-27 KiCad schematic (imported from the original Altium project), schematic PDF and image
    [cartouche-usb4.kicad_sch]
2026-09-27 Add section, underside and colour renders; BOM table in README
    Claude-Session: https://claude.ai/code/session_01RqDGjrUG4GdEsawKGChjmB
2026-09-27 JLCPCB BOM and placement files for assembly
    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
    [jlcpcb-bom.csv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]
2026-09-27 Enhance JOURNAL.md with project updates and images
    Added new sections on project goals, source design, and prototype preparation. Updated images and cost details.
2026-09-27 Update JOURNAL.md with project progress and scripts
    Documented website performance optimization efforts, open-source release structure, benchmark script for USB4 speeds, and KiCad BOM export automation.
2026-09-27 Update time tracking and enhance scripts and workflows
    Updated time spent on various tasks and added a new flag to the script for comparing JSON results. Enhanced the GitHub Actions workflow for automatic BOM regeneration and added unit tests for the par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
2026-09-28 Case v1.1: SSD at the connector datasheet height, printable mock-up with a card slot
    The SSD was 1.1 mm too low and 0.35 mm too deep (below the M.2 slot), and the
    board mock-up connector was solid. Fixed from the ARGOSY NASM0-S6701-TPH4
    datasheet; fit check is 0 mm3 everywhere.
    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
    [board_mockup.stl, case_base.step, case_base.stl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]
2026-09-28 Case v1.2: passive cooling (SSD thermal pad on a base boss, fins under the base)
    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
    [BOM.csv, case_base.step, case_base.stl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]
2026-09-28 BOM: quote the thermal pad note
    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
    [BOM.csv]
2026-09-28 Journal: the board runs too hot
    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
2026-09-28 Cooling diagram (heat path, to scale) in the README and the journal
    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
2026-09-28 Éclair Dock (under-desk holder) + airflow diagram and before/after cooling estimate
    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
    [BOM.csv, case_base.step, case_lid.step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]
2026-09-28 Journal: cooling entry with the heat-path, airflow and before/after diagrams; BOM total cost lines
    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
    [BOM.csv]
2026-09-28 Dock: 1:1 drilling template (PDF + generator), print-test notes
    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
2026-09-28 Case v1.3: LOTES M.2 connector (C841669), BOM update
    The ARGOSY NASM0-S6701-TPH4 (3.0 mm) is out of stock everywhere. The board
    footprint is the LOTES APCI0113-P001A's (H4.8, C841669), so CN1 moves to it:
    - SSD card face at 3.15 mm under the board (LOTES drawing), 1.25 mm lower
    - base 1.25 mm deeper, screw heads counterbored 1.25 mm (same screws)
    - case 25 x 65.7 x 15.6 mm, dock 29.9 x 73.8 x 27.2 mm; all fit checks 0
    - LED1 -> Everlight 16-213SDRC (C71911), a real 0402 red LED
    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
    [BOM.csv, board_mockup.stl, case_base.step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]
